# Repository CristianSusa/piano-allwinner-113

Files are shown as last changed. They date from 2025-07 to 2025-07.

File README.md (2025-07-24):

# Piano with Dev Board LCPI-PC-T113
This piano is a college project for Embedded Systems and Electronic Systems Design. It uses the LCPI-PC-T113 development board with the Allwinner T113s chip running embedded Debian. The project includes the design of the PCB as well as the design of the enclosure. Notes on the development process are also included.

## Contents
Within this repository, you will find two folders:
* embedded-systems-development
* electronic-system-design

These folders serve as a step-by-step guide on how to construct the piano. They include files, construction notes, and suggestions for improvements in future versions.

Enjoy :D

# The Project
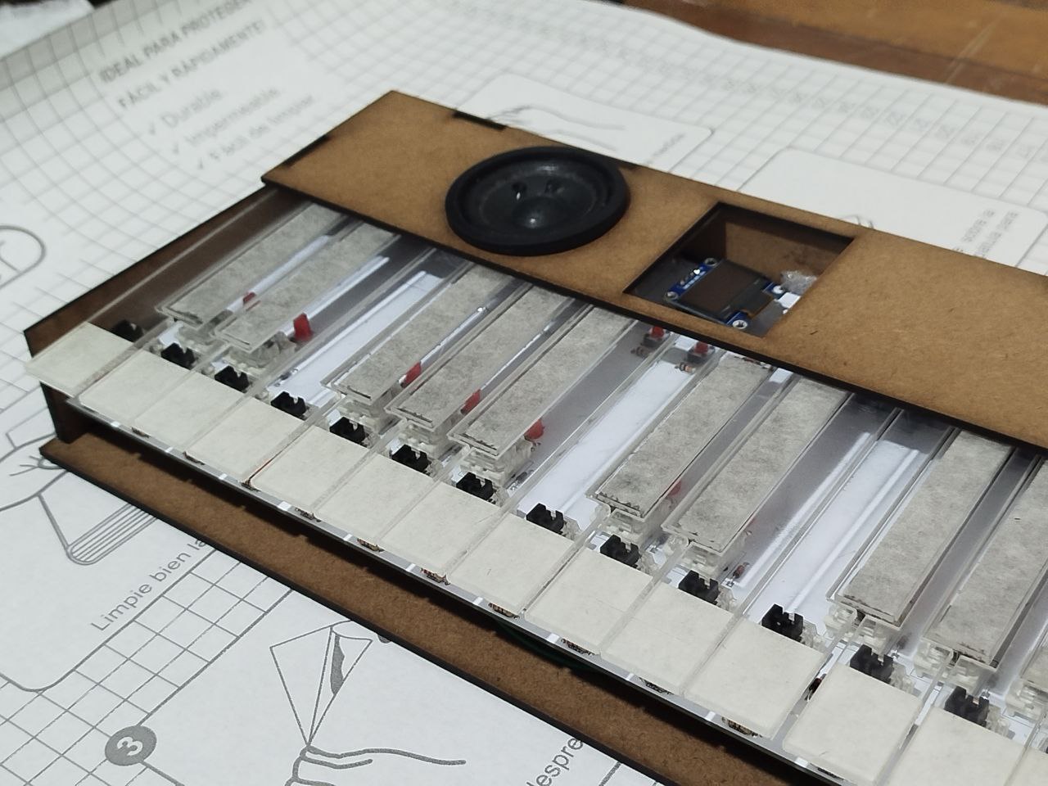
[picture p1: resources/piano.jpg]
piano-image


This piano is designed to provide a low-cost solution for portable musical instruments.

It has two main functions:

1. **Piano Mode** – When a key is pressed, the corresponding note is played through the speaker, just as you would expect from a traditional piano.

2. **Tutor Mode** – In this mode, a few preset songs are available. You can select one, and LEDs will light up to indicate which key to press next, guiding you through the melody step by step.

The piano is intended not only to function as a musical instrument, but also to serve as a learning tool for beginners.

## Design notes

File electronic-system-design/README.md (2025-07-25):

# Electronic Design
This section provides a detailed explanation of the project's electronic design, including key decisions, objectives, and development rationale. It aims to offer a broader perspective on the piano as a finished product, beyond just its functionality.

## The Piano
This project is a university-level design that combines embedded systems and electronic hardware development. It is built around the LCPI-PC-T113 development board, featuring the Allwinner T113s chip running embedded Debian.

The piano integrates both custom PCB and enclosure design, with additional documentation on the development process.

Its goal is to offer a low-cost, portable musical instrument that serves both as a basic piano and as an educational tool. It features two main modes:

- **Piano Mode** – Pressing a key plays the corresponding note through a speaker.
- **Tutor Mode** – LEDs guide the user through preloaded melodies, indicating which key to press next.

The system is designed for beginners, blending play and learning in a compact, accessible format.

## Inspiration
This piano is physically inspired by commercial MIDI controllers such as the **MiniLab 3** by Arturia, the **Akai MPK Mini**, and the **OP-1** by Teenage Engineering.

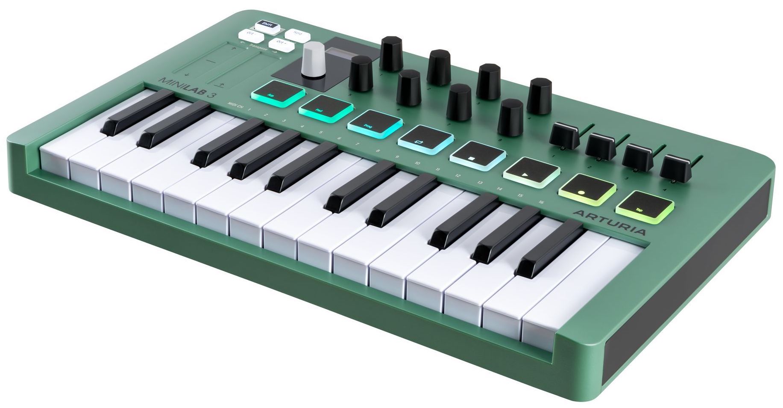
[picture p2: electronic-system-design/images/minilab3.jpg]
MiniLab 3

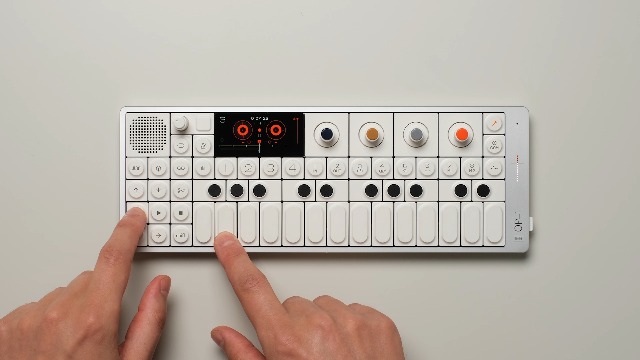
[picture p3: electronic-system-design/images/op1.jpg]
OP-1

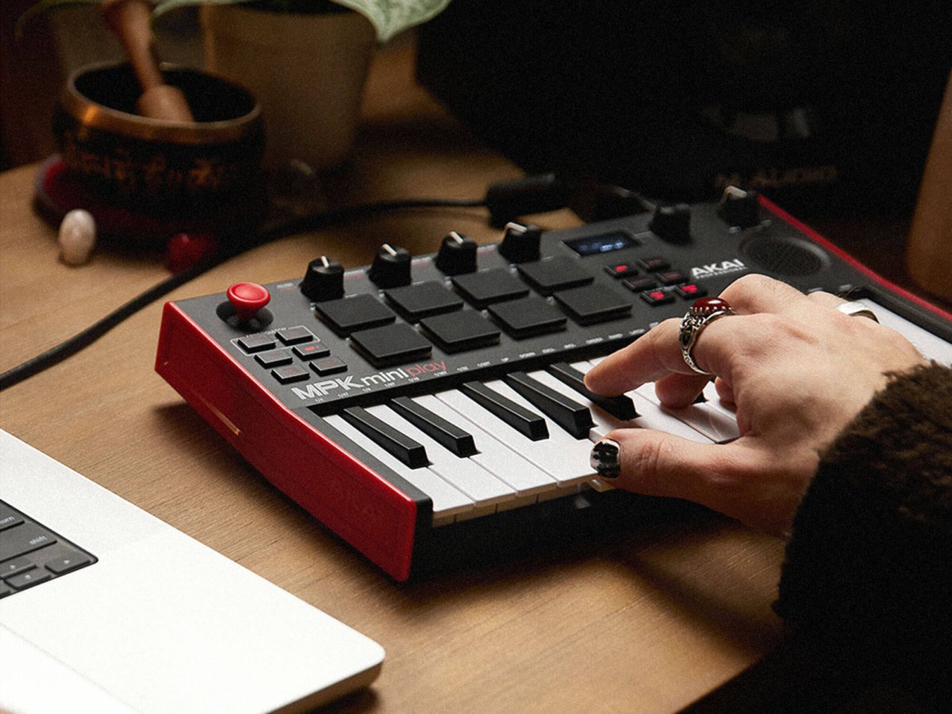
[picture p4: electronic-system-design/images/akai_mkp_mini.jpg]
Akai MPK Mini


The goal is to build a portable device that gives users easy access to a piano wherever they are.

## Objectives
The goal of this project is to create an affordable, efficient, and scalable digital keyboard that works as a standalone device. It features an intuitive user interface.

### Main Objective
Design and build an affordable, energy-efficient, and user-friendly digital keyboard with an intuitive interface, capable of functioning independently and suitable for educational or experimental use.

### Specific Objectives
- **Ensure accessibility and affordability** by keeping the total cost of components below $300,000 COP, making the device viable for students and academic institutions.
- **Promote usability and learning** by including exercises or songs, reinforcing its role as a musical tutor and learning tool.
- **Guarantee energy efficiency and portability** by ensuring the device operates with a current draw of less than 1.5 A, allowing it to be powered by a standard 5V / 2A USB adapter or computer.

## Block Diagram

The proposed system configuration uses the LCPI-PC-T113 development board, featuring the Allwinner T113-S3 chip, as the main controller. A custom daughterboard (the PCB designed in this course) interfaces with it to connect the piano peripherals.

This separation of boards allows modularity: the main board can be reused in future projects, while the daughterboard is application-specific.

The system consists of five main modules:

- **Piano Inputs** – Controls 25 keys (from C4 to C6, covering 2 octaves) arranged in a 5×5 matrix. A *74HC595* shift register activates the columns, while a *74HC165* shift register reads the row states.
  - Shift registers reduce the number of required GPIOs and allow scalable input/output control.
  - ✅ *Pro*: Efficient use of GPIOs with minimal pin usage.
  - ❌ *Con*: Adds a small delay due to serial communication and requires precise clocking.

- **User Interface** – Includes an OLED display and three menu buttons.
  - A minimal interface was chosen to ensure simplicity and ease of navigation for all users.
  - ✅ *Pro*: Clear feedback and interaction with minimal components.
  - ❌ *Con*: Limited interactivity and no text input options.

- **Piano Outputs** – Manages 25 LEDs (one per key) using two *74HC595* shift registers in a 5×5 matrix. Audio output is routed from the board’s headphone jack to an 8-ohm speaker.
  - Using a matrix configuration minimizes wiring and enables efficient LED control in tutor mode.
  - ✅ *Pro*: Clear visual guidance during learning.
  - ❌ *Con*: Cannot light multiple arbitrary combinations without flickering unless advanced multiplexing is implemented.

- **Power** – Powered via a USB-C port providing 5V @ 2A, allowing compatibility with standard smartphone chargers.
  - USB-C is a modern standard and widely available.
  - ✅ *Pro*: Universal and accessible power source.
  - ❌ *Con*: Some connectors have mechanical instability depending on the cable used.

- **Serial Communication and Data** – Includes SD card storage and USB to TTL serial communication used during development and booting.
  - External storage and serial communication simplify testing and firmware updates.
  - ✅ *Pro*: Easy debugging and access to external data.
  - ❌ *Con*: Required workaround (jumpers) due to missing TX/RX pins in the schematic.

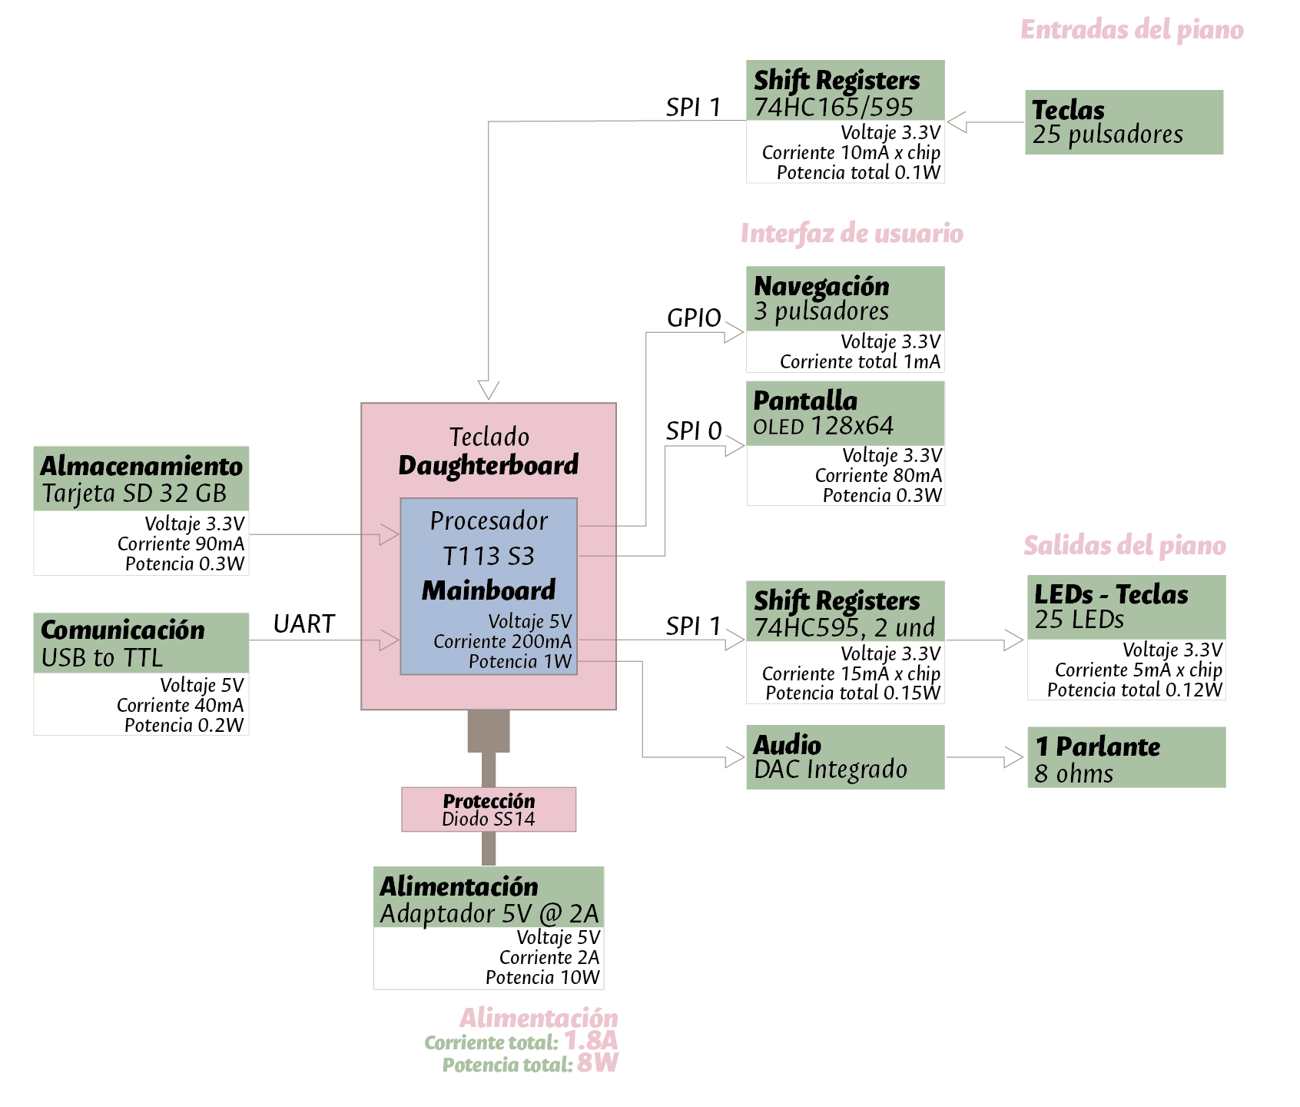
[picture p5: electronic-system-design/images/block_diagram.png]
block diagram


## Electrical Schematic

A total of 19 pins are used to connect the processor to the piano's peripherals. The image below shows the pinout configuration:

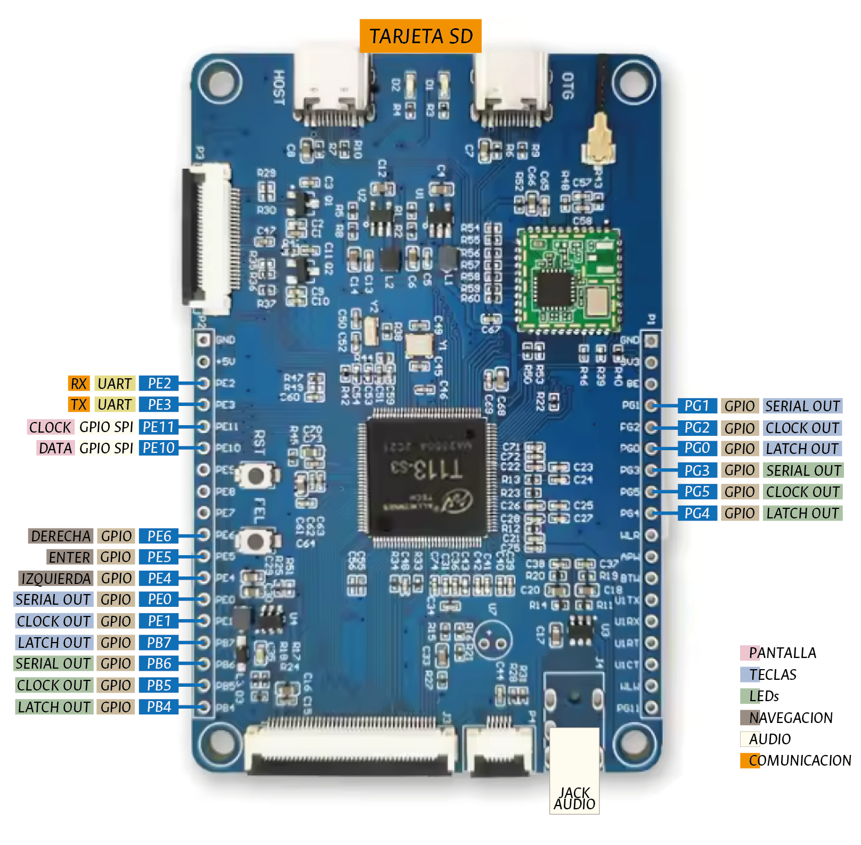
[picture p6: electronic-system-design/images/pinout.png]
pinout


This layout was chosen to optimize routing and prioritize low-latency signals, like the key matrix and OLED interface.

The following sections explain how each module works and how the components are connected. All images are taken from the project schematic file `piano_pcb.kicad_sch`, available at `./resources/pcb/piano_pcb`.

### Keys Matrix
A 5×5 matrix is used to detect key presses, allowing us to read 25 distinct notes. A *74HC595* shift register sequentially activates each column, and a *74HC165* reads the row values. The switches are configured with pull-down resistors: a pressed key outputs logic `1`, and an unpressed key outputs `0`.

- ✅ *Pro*: Scalable and compact solution for multiple key inputs.
- ❌ *Con*: Requires careful debouncing and timing control in software.

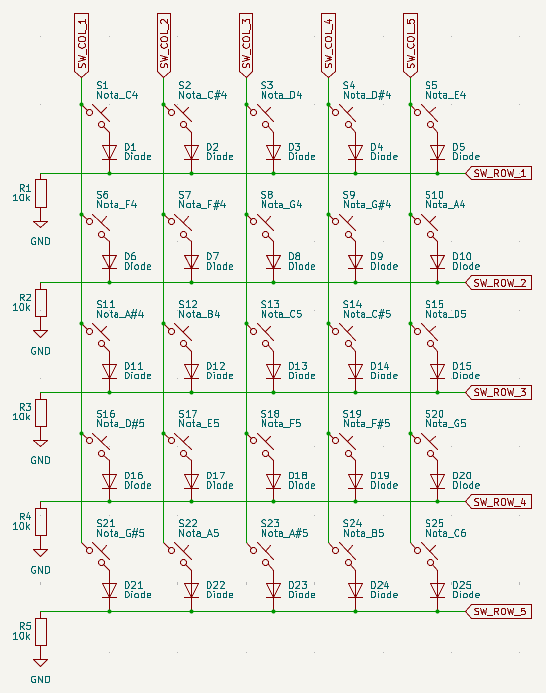
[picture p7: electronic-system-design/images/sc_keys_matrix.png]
sc_keys_matrix

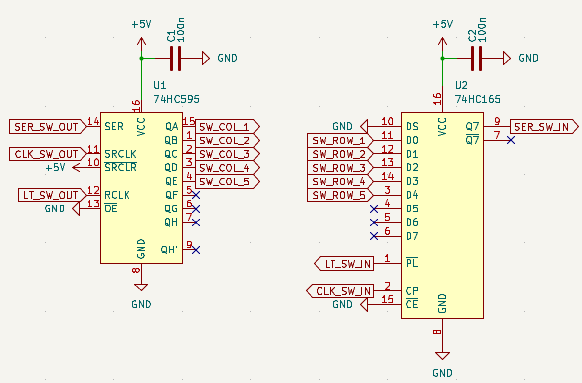
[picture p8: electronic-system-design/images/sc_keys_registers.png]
sc_keys_registers


### LEDs Matrix
Another 5×5 matrix is used to control the LEDs, which are mainly used in tutor mode to highlight the next key to press. Two *74HC595* shift registers manage the LED activation. LEDs use a pull-down configuration: a LED lights up when its cathode is at logic `1` and its anode is at logic `0`.

Coupling capacitors were used in the four integrated circuits to ensure proper power connection.

- ✅ *Pro*: Clean and organized visual feedback system.
- ❌ *Con*: Without current control, simultaneous activation of many LEDs can overload the system.

sc_leds_matrix
sc_leds_registers

### I2C Screen
Initially, a 240×240 SPI screen was proposed for the menu interface. However, due to technical issues and budget/time constraints, we opted for a 128×64 I2C OLED display using the SSD1306 controller.

- ✅ *Pro*: Easy to integrate, widely supported, and consumes less power.
- ❌ *Con*: Lower resolution limits UI complexity.

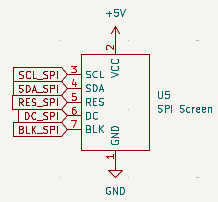
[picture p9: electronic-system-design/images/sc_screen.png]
sc_screen


### Menu Buttons
Three buttons (`Left`, `Enter`, and `Right`) allow the user to navigate the interface. All buttons use a pull-down configuration: pressing a button results in logic `1`, and releasing it results in logic `0`.

- ✅ *Pro*: Simple and intuitive user interaction.
- ❌ *Con*: Limited to basic menu navigation without multi-directional input.

Once the device is powered on and the application starts, the main menu is displayed with two options:

1. **Piano Mode** – Basic mode in which pressing a key plays the corresponding sound.
2. **Tutor Mode** – Guides the user through one of four built-in songs: `Estrellita`, `Cumpleaños Feliz`, `Los Pollitos`, and `Piratas del Caribe`.

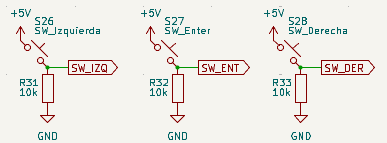
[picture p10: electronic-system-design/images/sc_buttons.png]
sc_buttons


### Power Input
Power is supplied through a USB-C female connector, chosen for its compatibility with most modern chargers. However, this decision turned out to be suboptimal — in practice, the connection can be unstable depending on the cable or connector, causing accidental shutdowns with slight movement.

To protect the circuit, an SS14 diode prevents reverse current and voltage spikes. Two 5.1kΩ resistors to ground ensure the USB-C port is used strictly for power and limits voltage to 5V.

- ✅ *Pro*: Broad compatibility and compact form factor.
- ❌ *Con*: Susceptible to disconnection if cable or socket is loose.

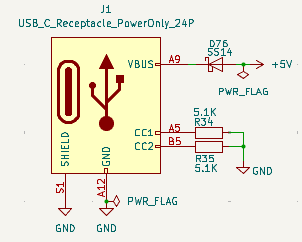
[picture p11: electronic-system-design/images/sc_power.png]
sc_power


### Dev Board Integration
A custom symbol and footprint were created in KiCad to represent the LCPI-PC-T113 board and ensure proper alignment of connections.

The schematic shows the necessary connections for:
- **Shift register control** – `SER`, `CLK`, `LATCH`
- **Menu buttons** – input GPIOs for `Left`, `Enter`, and `Right`
- **OLED display** – `SDA`, `SCL` for I2C communication

- ✅ *Pro*: Accurate mapping of dev board pins in PCB layout.
- ❌ *Con*: Omission of serial TX/RX was a critical error, requiring manual correction with jumpers.

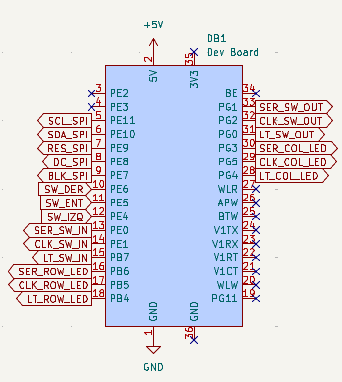
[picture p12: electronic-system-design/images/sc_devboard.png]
sc_devboard


The serial communication was originally assigned to pins `PE2` and `PE3`, as shown in the pinout image above. However, these connections were not included in the schematic — a design oversight. As a workaround, jumpers were added in the physical prototype. This is one of the areas identified for improvement in future revisions.

## Materials
The piano consists of low-cost electronic components, including standard switches, LEDs, and diodes. The two most expensive parts of the build are the LCPI-PC-T113 development board and the custom-designed daughterboard (PCB). These will be detailed further in the cost breakdown.

Below is a list of the main components used:

- 25 × Tactile switches (1 per key)
- 25 × Red LEDs (1 per key for tutor feedback)
- 25 × 220 Ω resistors (for LED current limiting)
- 50 × 1N4148 diodes (for matrix input protection)
- 8 × 10 kΩ resistors (for pull-down configurations)
- 3 × 4-leg tactile menu switches (Left, Enter, Right)
- 4 × 8×2 pin sockets (for shift register and board connections)
- 3 × 74HC595 shift registers (2 for LED matrix, 1 for key matrix column activation)
- 1 × 74HC165 shift register (for key matrix row reading)
- 4 × 100 nF ceramic capacitors (for decoupling)
- 1 × SS14 Schottky diode (for reverse polarity protection)
- 2 × 5.1 kΩ resistors (for USB-C power configuration)
- 1 × USB-C female port (for 5V power input)
- 2 × Female header grids (to interface with dev board)

All components were selected for availability, cost-efficiency, and compatibility with hand soldering and prototyping.

## PCB Design

KiCad and LayoutEditor were the main tools used to design the PCB. The complete KiCad project is available at `./resources/pcb/piano_pcb`.

Returning to our five main modules, this section covers the design process for each one.

---

### Piano Inputs

The key matrix relies on mechanical keyboard switches and diodes. [This video](https://www.youtube.com/watch?v=8WXpGTIbxlQ) provided valuable guidance on mechanical keyboard design and was used as a reference. Its symbol and footprint library was also integrated and is available in `./resources/pcb/piano_pcb/Resources`.

Each note has a dedicated LED, so the layout prioritizes compactness while replicating a traditional piano key arrangement. Diodes are placed to the left of each key to prevent ghosting, and LEDs are positioned above or below the switch based on the note's vertical position.

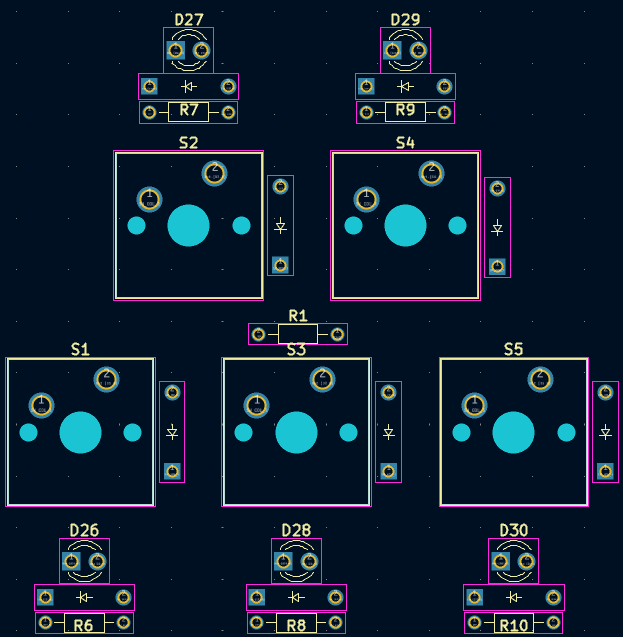
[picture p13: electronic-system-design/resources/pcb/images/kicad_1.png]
kicad_1

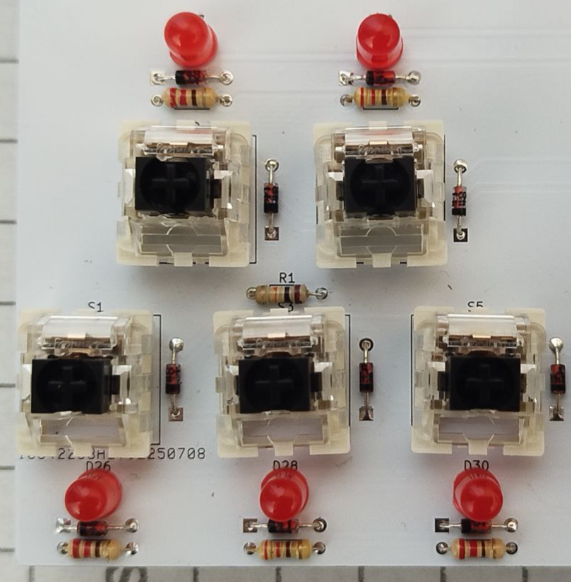
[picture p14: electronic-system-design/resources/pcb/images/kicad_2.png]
kicad_2


Footprint used for the key switches:

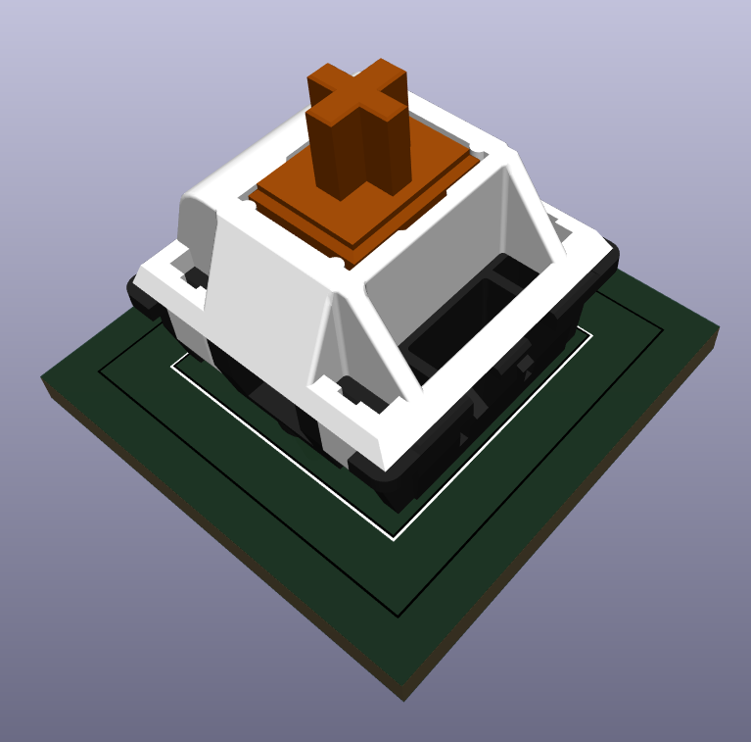
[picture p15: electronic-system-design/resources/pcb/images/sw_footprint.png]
sw_footprint


### Piano Outputs

The LEDs are a core feature for the tutor mode. Each LED has a dedicated 220 Ω current-limiting resistor and a 1N4148 diode to avoid unwanted activation due to matrix effects (ghosting).

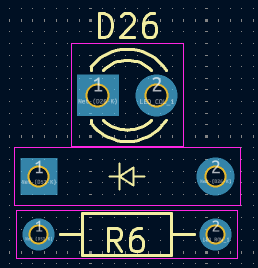
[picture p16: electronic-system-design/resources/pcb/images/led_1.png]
led_1

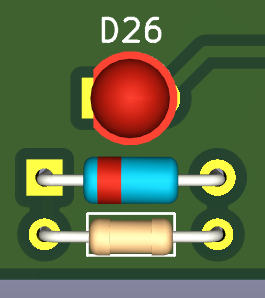
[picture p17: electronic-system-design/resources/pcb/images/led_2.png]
led_2

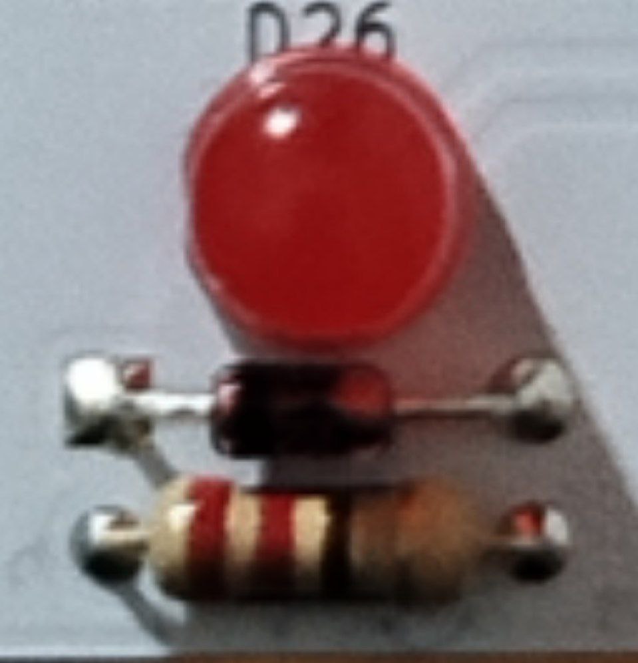
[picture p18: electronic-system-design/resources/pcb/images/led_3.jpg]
led_3


### User Interface

The menu buttons and display are located on the top edge of the piano for visibility and accessibility. The OLED screen symbol and footprint were manually created based on an initial SPI version, though later adapted to a 128×64 I2C display (SSD1306). The chosen I2C pins remained the same for mechanical compatibility.

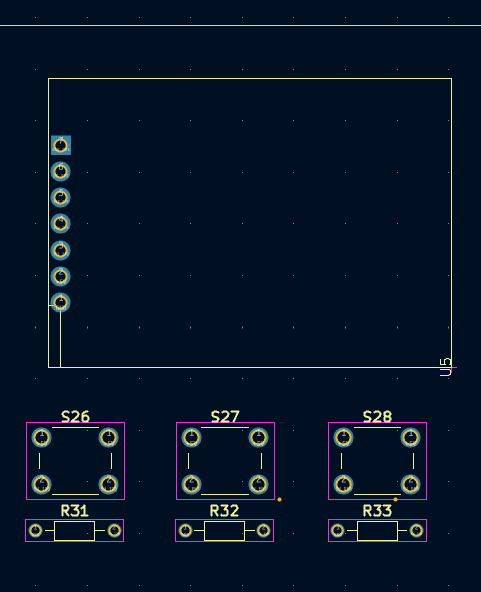
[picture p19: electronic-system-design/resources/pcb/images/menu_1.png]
menu_1

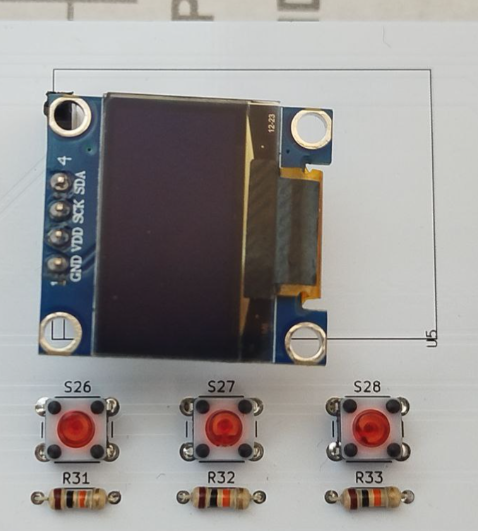
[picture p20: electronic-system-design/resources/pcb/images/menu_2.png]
menu_2


### Power Input

This section presented the most soldering challenges due to two surface-mount components: the USB-C female connector and the SS14 Schottky diode. These were the only compatible models available in the local market and required careful placement.

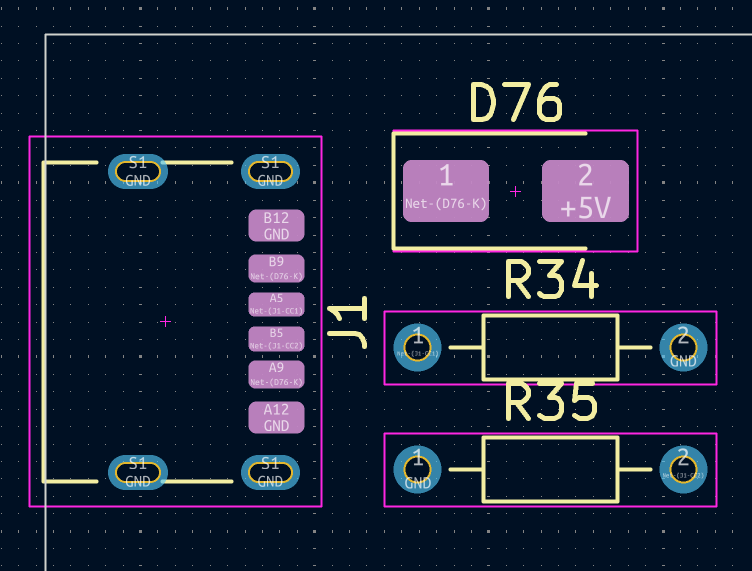
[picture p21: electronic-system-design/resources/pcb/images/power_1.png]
power_1

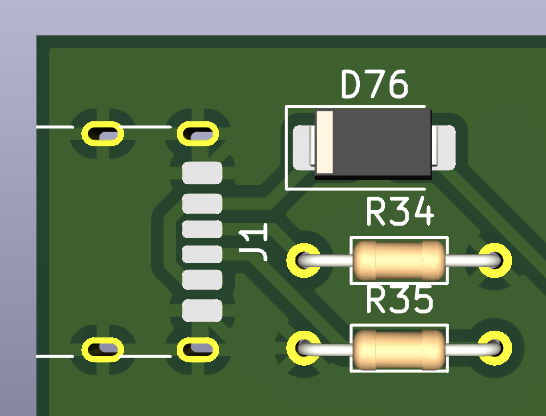
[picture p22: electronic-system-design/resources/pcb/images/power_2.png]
power_2

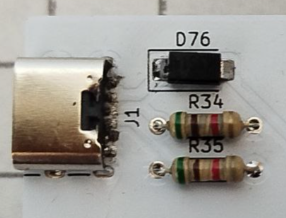
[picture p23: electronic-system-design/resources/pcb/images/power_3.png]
power_3


### Devboard Interface

A custom footprint was created to place female headers in a "shield-like" fashion, aligning with the LCPI-PC-T113 board’s pinout. This allows reliable and modular interfacing between the devboard and the daughterboard.

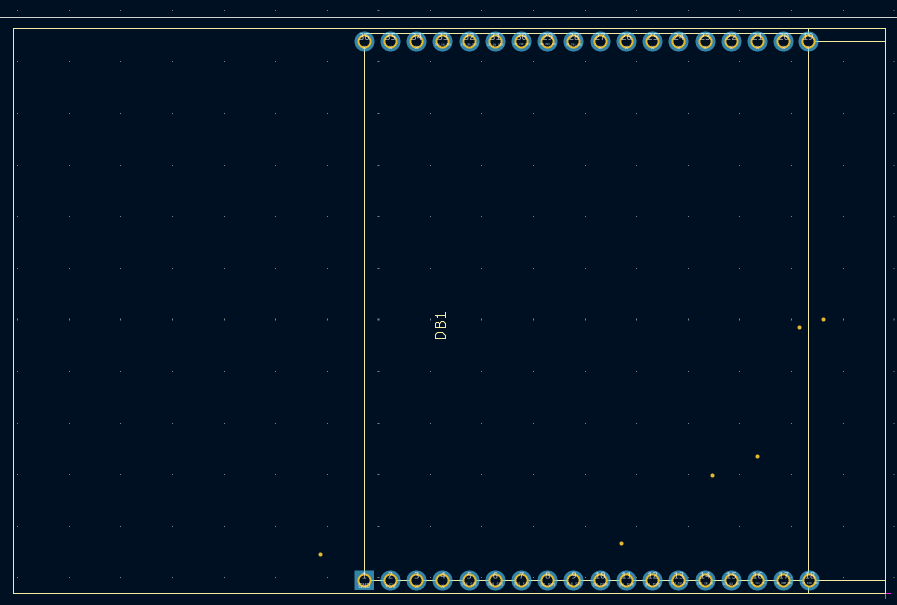
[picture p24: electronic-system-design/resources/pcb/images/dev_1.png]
dev_1


---

### Construction

The PCB routing was done using the `FreeRouting` tool. All traces were set to 0.5 mm width, which is sufficient given the low current requirements of each signal. Both top and bottom layers were used, with several vias placed throughout the board—particularly around the key and LED matrices—due to the high density of connections.

The PCB was manufactured by **JLCPCB**, and the production files are available at `./resources/pcb/piano_pcb/production`.

Below are some images of the PCB layout and the assembled board:

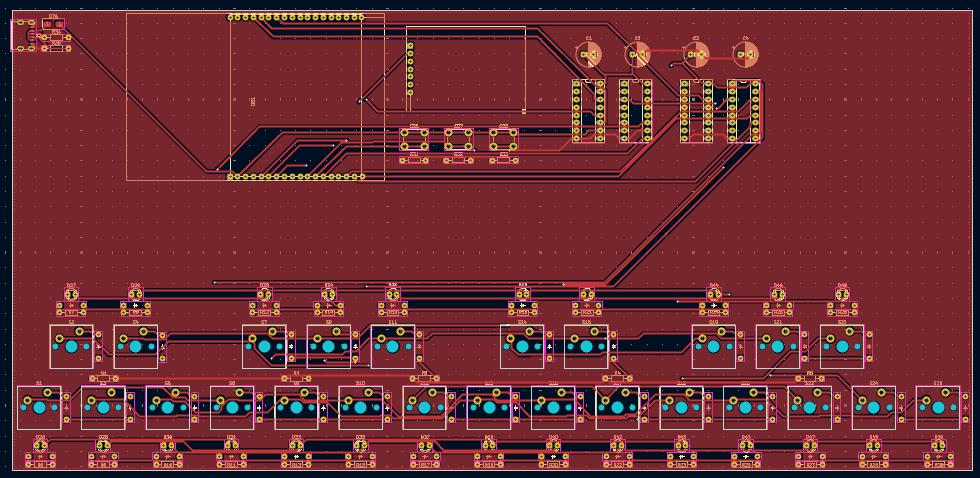
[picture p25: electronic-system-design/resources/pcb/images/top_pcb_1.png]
top_pcb_1

top_pcb_2
bot_pcb_1
bot_pcb_2

final_pcb_kicad

Final soldered board:

final_pcb

## Case Design

The case was designed using **Adobe Illustrator**, vectorizing the pieces for laser cutting. The main PCB measures **314 mm × 150.5 mm**, and additional clearance was considered for the height of the devboard underneath (~15 mm), as well as the switches and screen above (~17.5 mm).

The design consists of two main parts:

1. **The Case** – Made of MDF and laser cut to encase the piano. It protects the electronics and gives structural support.

mdf

2. **The Keycaps** – A piece of laser-cut acrylic simulates the shape of piano keys. The transparency allows LED light to shine through during tutor mode, guiding the user visually.

acr

The Adobe Illustrator and PDF files used in the process are available at `./resources/case/files`.

### Case Construction

Once all pieces were laser cut, assembly was done manually. The result is a lightweight, solid enclosure with custom-fit keycaps:

case_1
case_2
case_3

## User Menu

As mentioned earlier, three buttons (`Left`, `Enter`, and `Right`) are used to navigate the user interface. All buttons follow a pull-down configuration: pressing a button sends logic `1`, and releasing it returns to logic `0`.

Upon powering on the device and loading the main application, the user is presented with the main menu featuring two options:

1. **Piano Mode** – A classic mode where each key press immediately plays a corresponding note.
2. **Tutor Mode** – A guided mode where the user can select one of four built-in songs: `Estrellita`, `Cumpleaños Feliz`, `Los Pollitos`, and `Piratas del Caribe`.

Below is a simplified flow diagram of the navigation logic:

flow_diagram

Some photos of the interface in action:

oled_1
oled_2

## Prototype
The final piano is a mix of effort, enthusiasms, challenges, copper, mdf, acrilic, electrons and music. Here are some photos.

pro_1
pro_2
pro_3
pro_4

## Technical Decisions Justification

### Choice of Main Microcontroller or IC
The project uses the **LCPI-PC-T113** development board based on the **Allwinner T113-S3** processor. This chip was selected because it can run a full embedded Debian OS, providing enough processing power to handle multiple peripherals (display, inputs, outputs, audio) while offering flexibility for expansion. Its ability to support real-time applications (like those built with Faust) made it an ideal platform for this kind of project.

### Technology Type: THT, SMD, or Mixed
A **mixed technology approach** was used. Most components (resistors, diodes, capacitors, shift registers, buttons, LEDs) are **THT (Through-Hole Technology)**, selected for ease of manual soldering and local availability. However, some components such as the **USB-C connector** and the **SS14 diode** are **SMD (Surface-Mount Device)** because they were only available in that format.

This hybrid approach balanced manufacturability, cost, and the team's ability to assemble the board by hand.

### Number of Layers
The PCB was designed with **two layers (top and bottom)**. This was necessary to route the large number of signals—especially in the key and LED matrices—without increasing manufacturing costs. Vias were used to interconnect the layers where needed, allowing for a more compact and efficient layout.

### Power and EMI Considerations
Power is supplied through a **USB-C female connector**, delivering 5 V at 2 A. A **Schottky SS14 diode** was added to protect the circuit from reverse current or voltage spikes. Two **5.1 kΩ pull-down resistors** ensure the port is used for power only. The overall current draw of the system is low, so thermal or EMI (electromagnetic interference) concerns were minimal. However, filtering and shielding could be added in future revisions if needed.

### Standards Applied
While no formal certification standard was strictly followed, the design referenced general best practices from the **IPC-2221** standard, including trace width, clearance, and via placement. These practices helped ensure a manufacturable PCB and reliable electrical performance during testing.

---

## Possible Improvements

- **Redesign the pinout** to include the `TX` and `RX` serial communication lines. These were missing in the original schematic and had to be patched with jumpers on the prototype.
- **Replace or reposition the USB-C connector** to improve physical connection stability. In its current location, small movements can interrupt power and shut down the piano.
- **Use dedicated LED drivers**, such as the TLC5940, to enable PWM per channel, reduce sound delay, and allow multiple notes to play simultaneously (polyphony).
- **Reintroduce the SPI screen** if software support issues are resolved, to take advantage of its higher resolution for better UI design.
- **Optimize power consumption** by adding sleep modes or auto-shutdown after inactivity.
- **Add EMI protection and filtering** for use in more demanding environments or for future compliance with electronic certification.
- **Follow full IPC standards** (such as IPC-2222 for general-purpose PCBs) to improve reliability, documentation quality, and potential for scaling production.

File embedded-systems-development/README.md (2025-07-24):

# Embedded System
This part of the piano project follows the instructions provided by Carlos Iván Camargo Bareño, our instructor for the semester. He shared a book and a guide detailing how to set up the embedded system on our board. The text is available in the `resources` folder for further reference.

We chose the LCPI-PC-F133-T113-D1S-V1.3 development board, available at AliExpress.

This board features a dual-core ARM Cortex-A7 CPU, powered by the Allwinner T113-S3 SOC.

1. [Buildroot](#buildroot)
    1. [Clone the repository](#1-clone-the-repository)
    2. [Kernel configuration](#2-kernel-configuration)
    3. [Toolchain](#3-toolchain)
    4. [U-boot setup](#4-u-boot-setup)
    5. [Creating the SD](#5-creating-the-sd)
    6. [Creating image](#6-creating-image)
    7. [Debian](#7-debian)
    8. [Enjoy](#8-enjoy)
2. [Pins and Peripherals](#pins-and-peripherals)
3. [Device Tree](#device-tree)
    1. [The .dtsi File](#the-dtsi-file)
    2. [The .dts File](#the-dts-file)
4. [Rebuilding](#rebuilding)
5. [The Code](#the-code)
    1. [Matrices](#matrices)
    2. [Sound](#sound)
    3. [Screen](#screen)
    4. [Main Menu](#main-menu)
6. [The piano](#the-piano)

## Buildroot
Buildroot is a tool that helps in the construction of embedded systems, similar to Yocto, OpenWRT, and other build systems. We are using Buildroot to create the system image. Below is the step-by-step guide.

### 1. Clone the repository
First, you will need to run this commands:

```
git clone https://github.com/yuzukihd/Buildroot-YuzukiSBC
cd Buildroot-YuzukiSBC
source envsetup.sh
lunch
make mangopi_mq_dual_defconfig
make -j10 # Adjust according your machine, running the nproc command on the terminal helps
```
You will encounter three errors during this process. While running `make`, it will attempt to download some files that are no longer available at the specified URLs. Here's how to resolve them:

1. Within the `resources` folder you have `v1.0.1.tar.gz`. You should move this file to `buildroot/dl/uboot/`.
2. Within the `resources` folder you have `1.0.0.tar.gz`. You should move this file to `buildroot/dl/linux`.
3. Within the `resources` folder you have `mkbootimg`. You should move this file to the folder of binaries of your computer, you can use `cd /bin/` and copy the file.
4. Other errors may advise you to install different packages, they are usually available with `apt-get install`.

### 2. Kernel configuration
The last step was executed using the default configuration. Now, we need to modify the configuration file to add support for the specific devices we want to use. Run the following command to open the menu configuration:
```
make linux-menuconfig
```
Now, make sure to enable (or disable) the following nodes:
```
Device Drivers
    GPIO Support --->
        <*> /sys/class/gpio/
        <*> Debug GPIO calls

Device Drivers
    Network device support --->
        PHY Device support and infrastructure --->
            < > RealTek RTL-8363NB Ethernet Adapter support

Device Drivers
    I2C support --->
        I2C Hardware Bus Support --->
            <*> GPIO-based bitbanging I2C

Device Drivers
    Graphics support --->
        Frame buffer Devices --->
            <*> Support for frame buffer devices --->
                [*] Simple framebuffer support
                <*> Solomon SSD1307 framebuffer support

File systems
    <*> Old Kconfig name for Kernel automounter support
    <*> Kernel automounter support (supports v3, v4 and v5)
    < > SquashFS 4.0 - Squashed file system support

General setup
    <*> Control Group support
    [*] Support for paging of anonymous memory (swap)
```
You can now rebuild your image with the following commands
```
make -j12 linux-rebuild
make -j12
```

### 3. Toolchain 
These tools will help us in the compilation proccess, the `TOOLCHAIN` folder is available at `resources`.
Just make sure to add the this folder to the path with `export PATH=$HOME/TOOLCHAIN/gcc-linaro-7.2.1-2017.11-x86_64_arm-linux-gnueabi/bin:$PATH`

### 4. U-boot setup
Within the `resources` folder you also have the `v1.0.1.tar.gz` folder. You need to unpack that and patch the instructions with some files available at `patch_uboot`, also available in `resources`. This way:

```
tar zxvf v1.0.1.tar.gz
cd u-boot-2018-1.0.1

patch -p1 < ../patch_uboot/0001-add-support-for-buildroot.patch
patch -p1 < ../patch_uboot/0002-fix-uboot-disable-dtc-selfbuilt.patch
patch -p1 < ../patch_uboot/0003-fix-uboot-support-for-buildroot-dts-file.patch
patch -p1 < ../patch_uboot/0004-fix-No-rule-to-make-target-sunxi_challenge.patch
patch -p1 < ../patch_uboot/0005-fix-yylloc.patch

cp ../patch_uboot/uboot_mangopi_mq_dual_defconfig configs/
cp ../patch_uboot/sun8i-mangopi-mq-dual-uboot.dts ./arch/arm/dts/
cp ../patch_uboot/sun8iw20p1-soc-system.dtsi arch/arm/dts/
```
You’ve just copied a `.dts` and a `.dtsi` file. These are **not** the device tree files you will modify for future tests involving pins in your project. They are basic device tree files used to initialize essential hardware and boot the root filesystem.

For pin configuration and other hardware customizations, you’ll need to locate and edit the appropriate board-specific device tree files later in the process. We will check that in a second.

Now, you need open the menu configuration:

```
make CROSS_COMPILE=arm-linux-gnueabihf- ARCH=arm uboot_mangopi_mq_dual_defconfig
make CROSS_COMPILE=arm-linux-gnueabihf- ARCH=arm menuconfig
```
and make sure to enable the following options
```
Command line interface --->
    Boot commands --->
        [*] bootz
    [*] go

Device Tree Control --->
    Provider of DTB for DT control --->
        [*] Provided by the board at runtime
```
And make the instructions:
```
make CROSS_COMPILE=arm-linux-gnueabihf- ARCH=arm
```
At the end, you will have a file named `u-boot-sun8iw20p1.bin`. Please copy this file to `your-path/Buildroot-YuzukiSBC/buildroot/output/images`. We will need that file in the future;)

### 5. Creating the SD
Finally, we are going to create the partitions and add the necessary files to our SD card to make everything work.

According to the image:
buildroot_table

* `boot_package.fex` includes `u-boot-sun8iw20p1.bin` and `sun8i-mangopi-mq-dual-linux.dtb`. These are essential for the initial boot stage of the system.
* `boot.vfat` includes `boot.img`, `zImage`, and `sun8i-mangopi-mq-dual-linux.dtb`. These files contain the kernel, device tree, and bootloader required to start the operating system.

First, we have to copy the `boot_package.fex` on the requiered location, please run the following commands:
```
cd your-path/Buildroot-YuzukiSBC/buildroot/output/images
./dragonsecboot -pack boot_package.cfg
sudo dd if=boot_package.fex of=/dev/sdX(CHANGE) bs=1k seek=16400
```
We have just completed the initial boot. Now, we need to ensure that the partitions are correctly created on the SD card and have the appropriate sizes.
```
cd your-path/Buildroot-YuzukiSBC/buildroot/output/images
sudo dd if=sdcard.img of=/dev/sdX(CHANGE)

sudo fdisk /dev/sdX(CHANGE)

Command (m for help): p

Device          Start   End         Sectors     Size    Type
/dev/sda1       35360   36383       1024        512K    Linux filesystem
/dev/sda2       36384   36639       256         128K    Linux filesystem
/dev/sda3       36640   36895       256         128K    Linux filesystem
/dev/sda4       36896   102431      65536       32M     Linux filesystem
/dev/sda5       104448  62333918    62229471    29,7G   Linux filesystem
    
Borrar partición: d
Crear nueva partición n
Gardar cambios: w
```
These steps resize the fifth partition. Now, we just need to format it with the correct filesystem.

```
sudo mkfs.ext4 /dev/sdX5(CHANGE)
```
**PLEASE UNPLUG AND PLUG ONCE AGAIN THE SD CARD TO MAKE SURE THE CHANGES ARE SAVED**

### 6. Creating image
Now, we just need to add the image to our SD Card with the following commands:
```
cd your-path/Buildroot-YuzukiSBC/buildroot/output/images
mkbootimg --kernel zImage --output boot.img
sudo cp zImage boot.img sun8i-mangopi-mq-dual-linux.dtb /media/USER/FOURTH-PARTITION/ # That fourth partition is usually something with 8 characters like 12B7-6A23 in my case
```

### 7. Debian
The last step is to load an OS to the SD Card.
Within the `resources` folder you have `debian_bookworm`. You just need to copy the files into the fifth partition, the one we just resized.
```
cd your-path/debian_bookworm
sudo cp -avr * /media/USER/FIFTH-PARTITION/  # That fifth partition is usually something with a lot of characters like d4ab1e98-2104-4b8f-8526-55a987f8b082 in my case
```
For further details on this process, the guidebook contains a step-by-step guide on how to download and set up the OS.

### 8. Enjoy
Now you're all set! You can communicate with your board from your computer over the serial connection using Minicom. :D

## Pins and Peripherals
As mentioned at the beginning, this project aims to be a tutor for piano learners. To accomplish that, we need to have three main things:

* A piano keyboard that sounds
* A system to guide the user on which key to press next
* A menu interface for the user to interact with the device

We proposed the construction of a daughter board, a shield-like board, with the necessary elements to achieve our three specifications. More details on this process are provided in another section of this repo, `electronic-system-design`, which includes files, key points of the design, the methodology used, and the physical construction of the piano.

However, it is important to mention a couple of things here regarding the pinout.

This board has 36 pins, some of which are part of the PB, PE, and PG banks of pins. More information on that can be found in the documentation included in  [this documentation](https://drive.google.com/drive/folders/1lrqDsxtGl8WvU7o547lT9IkHwGyAHXFU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)

We used MIDI controllers like the MINILAB3, AKAI MPK Mini, and OP-1 from Teenage Engineering as references for our piano. They have 25 keys from C4 to C6.

For the tutor, we proposed one LED per key to instruct the player on "the next key to be pressed."

That is, 25 keys with 25 LEDs. The pins are limited on the board, so we have to reserve some for serial communication, the I2C screen, and some buttons.

The solution is to set up a 5x5 matrix for the keys and a 5x5 matrix for the LEDs, controlled by shift registers. This way, we reduce the pin count from 10 pins for each matrix (20 pins total for keys and LEDs) to just 12 pins, like this:

* Keys: the **74HC595** will activate the columns of the matrix, while the **74HC165** will read the values.
* LEDs: one **74HC595** will activate the columns of the matrix, and the other **74HC595** will activate the rows.

Each shift register uses three pins, and we have four integrated circuits, so that’s 12 pins for the matrices.

The screen, initially proposed to be SPI, was changed to I2C with bit-banging, and 3 buttons are used for the user interface.

Those are the pins used for this project. Below, you will find some images for further reference.

### Keys Matrix
keys_matrix
keys_shifts

### LEDs Matrix
leds_matrix
leds_shifts

### Screen and Buttons
screen_menu
buttons_menu

### Dev Board Pinout
dev_board_pinout

## Device Tree
This is how we set up the pins to interact with our kernel and the OS. Here, we define what each pin is used for and which drivers they should include. This is essential when customizing an image to ensure the pins are used correctly.

Keeping the pinout in mind, we configure the pins connected to a shift register or to a button for GPIO. The 3 pins for the screen are also GPIO but are used with I2C bit-banging.

### The .dtsi File
This is a general configuration. Here, we define the pins for the matrices, screen, buttons, and UART. You can see that all of them have `status = "disabled";`. This is for convention; they will be enabled in the next important file, the `.dts`.

You can find this file in `your-path/Buildroot-YuzukiSBC/buildroot/board/allwinner-generic/sun8i-t113/dts/linux/sun8iw20p1-linux.dtsi`

These are the nodes:

#### UART
For serial communication.
```
/ {
    soc: soc@3000000 {
        uart0: uart@2500000 {
            compatible = "allwinner,sun8i-uart";
            device_type = "uart0";
            reg = <0x0 0x02500000 0x0 0x400>;
            interrupts = <GIC_SPI 2 IRQ_TYPE_LEVEL_HIGH>;
            sunxi,uart-fifosize = <64>;
            clocks = <&ccu CLK_BUS_UART0>;
            clock-names = "uart0";
            resets = <&ccu RST_BUS_UART0>;
            uart0_port = <0>;
            uart0_type = <2>;
            status = "disabled";
        };
    }
}
```

#### Keys Matrix, LEDs Matrix, and Buttons
Here, we set the pins to `gpio_in`, making each pin a GPIO port that we can configure via software to send or receive data.
```
/ {
    soc: soc@3000000 {
        pio: pinctrl@2000000 {
            gpio_piano_pins: gpio_piano_pins@0 {
                pins = "PE0", "PE1", "PE4", "PE5", "PE6", "PB7",
                    "PG0", "PG1", "PG2", "PG3", "PG4", "PG5",
                    "PB4", "PB5", "PB6";
                function = "gpio_in";
                drive-strength = <10>;
                bias-disable;
            };
        }
    }
}
```

#### I2C Screen
We define the clock and data pins for the screen. Additionally, we configure some settings of our OLED display, such as width, height, and the driver `ssd1306fb-i2c`. This driver was included in the kernel configuration.
```
/ {
    i2c_gpio: i2c-gpio {
        compatible = "i2c-gpio";
        gpios = <&pio 4 10 GPIO_ACTIVE_HIGH /* SDA = PE10 */
                    &pio 4 11 GPIO_ACTIVE_HIGH>; /* SCL = PE11 */
        i2c-gpio,delay-us = <5>;
        #address-cells = <1>;
        #size-cells = <0>;
        status = "disabled";

            oled_display: oled@3c {
                compatible = "solomon,ssd1306fb-i2c";
                reg = <0x3c>;
                solomon,width = <128>;
                solomon,height = <64>;
                solomon,page-offset = <0>;
                solomon,com-offset = <0>;
                solomon,segment-offset = <0>;
                status = "okay";
            };
    };
}
```

### The .dts File
This is a more specific file with the header `#include "sun8iw20p1-linux.dtsi"`, meaning that includes our previous nodes configuration. Here we enable our devices along with the pins.

You can find this file in `your-path/Buildroot-YuzukiSBC/buildroot/board/mangopi/mq-dual/dts/linux/sun8i-mangopi-mq-dual-linux.dts`

#### UART
```
&uart0 {
	pinctrl-names = "default", "sleep";
	pinctrl-0 = <&uart0_pins_a>;
	pinctrl-1 = <&uart0_pins_b>;
	status = "okay";
};
```

#### Keys Matrix, LEDs Matrix, and Buttons
```
&pio {
    gpio_piano_pins: gpio_piano_pins@0 {
        allwinner,pins = "PE0", "PE1", "PE4", "PE5", "PE6", "PB7",
                "PG0", "PG1", "PG2", "PG3", "PG4", "PG5",
                "PB4", "PB5", "PB6";
        allwinner,function = "gpio_in";
        allwinner,muxsel = <0>;
        allwinner,drive = <1>;
        allwinner,pull = <0>;
    };
}
```

#### I2C Screen
```
&i2c_gpio {
    status = "okay";
};
```

## Rebuilding 
After making any changes within your device tree, you should:

1. Rebuild your image
2. Copy `boot_package.fex` to the appropriate location
3. Copy `boot.img` and `sun8i-mangopi-mq-dual-linux.dtb` to the appropriate location

```
## 1.
make -j10 linux-rebuild
make -j10

## 2.
cd your-path/Buildroot-YuzukiSBC/buildroot/output/images
./dragonsecboot -pack boot_package.cfg
sudo dd if=boot_package.fex of=/dev/sdX(CHANGE) bs=1k seek=16400

## 3.
cd your-path/Buildroot-YuzukiSBC/buildroot/output/images
mkbootimg --kernel zImage --output boot.img
sudo cp zImage boot.img sun8i-mangopi-mq-dual-linux.dtb /media/USER/FOURTH-PARTITION/ # That fourth partition is usually something with 8 characters like 12B7-6A23 in my case
```

---
## The Code
Once the devices and pins are configured, and both the kernel and OS are running, we can start working with the code and building applications.

Most of the development was done directly on the board’s processor via serial port commands. There is only one exception: when working with Faust (more on that later). The general workflow was:

```
# 1. Create the .cpp file
nano your-code.cpp

# 2. Compile it using the appropiate flags, most of the time the -lgpiod since with are working with gpio libraries
g++ your-code.cpp -o your-code -lgpiod

# 3. Test it
./your-code
```

For this project, we started by controlling the shift registers to verify that both the key matrix and the LED matrix worked properly.

Some test code is included in the `code/test_code` folder:

- For the **LED matrix**, the file `test_leds.cpp` turns on the LEDs on the PCB sequentially, from C4 to C6.
- For the **OLED display**, `test_oled_clear_screen.cpp` paints the screen either black or white. This was used to ensure the driver was functioning correctly and the display was receiving data.  

Additionally, the file `test_oled_draw.cpp` tests drawing an image of Patrick (from *SpongeBob*). This helped us understand how image data is handled by the OLED and what to keep in mind when displaying custom graphics.

A key component of the project is sound generation. We used [Faust](https://faust.grame.fr/) to generate sine waves. Starting from a `.dsp` file, we compiled it into an executable that drives the speaker. Here’s how:

```
# 1. Create the .dsp file
nano your-note.dsp

declare options "[osc:on]";
import("stdfaust.lib");
process = os.osc(440.00);
```

```
# 2. Construct the .cpp file and compile it

faust -a alsa-console.cpp -o your-note.cpp your-note.dsp
g++ your-note.cpp -o your-note -lasound

# You will note that the instructions on the guidebook are different, more on that later
```

```
# 3. Test it, your speaker must vibrate 440 times per second

./your-note 
```
Now, let’s take a closer look at the specific code used in this project.

### Matrices
Starting with the keys and LEDs, the file `code/piano/read_notes.cpp` defines the pins used according to the schematic and board pinout. In this setup, the columns are activated one by one while the rows are scanned to detect which key is being pressed. Thanks to a fast sampling rate, key presses are registered quickly, allowing smooth playability.

Due to limitations with how sound is compiled and triggered, we currently detect and play only one note at a time — even though the hardware is capable of detecting multiple simultaneous key presses.

In the tutor mode code — for example, `code/tutor/t_estrellita.cpp` — pin definitions are also provided. It’s important to note that both the key matrix and the LED matrix are configured with **pull-down resistors**, so ensure the logic in the code matches this configuration to avoid unexpected behavior.

### Sound
Once we know which key has been pressed, we need to generate the corresponding sound. In the official guidebook, interrupts are used for this purpose. However, since we’re working with shift registers rather than traditional GPIOs, we couldn’t use interrupts as expected.

Additionally, Faust’s OSC control (used to dynamically change values like frequency) did not work correctly on our team’s development machines. Because of this, we opted to generate each note individually using Faust, from C4 to C6. Each key is mapped to a specific precompiled sound executable.

This was the best working solution at the time, though it comes with some limitations:

- There’s a slight delay between pressing a key and hearing the sound.
- Only one note can be played at a time, even though the hardware can detect multiple key presses.

The 25 individual notes are available in the `code/piano/notes` folder.

### Screen
After some unsuccessful attempts to use an SPI screen, we switched to a more common I2C OLED screen with an SSD1304 controller. Using GPIO bitbanging, we were able to control the screen and display images.

To generate the bitmaps, we used the tool [img2cpp](https://javl.github.io/image2cpp/). However, since the driver was displaying the images incorrectly, we had to manually mirror them before embedding.

You’ll find the screen-related code in `code/oled/o_menu_normal.cpp` and related files. The bitmap is the only thing that changes between files — the rest of the code remains the same.

### Main Menu
To unify all the "modules" and create a simple user interface, we developed `code/main_code.cpp`. This file handles the input from the menu switches and lets you navigate a basic menu. From there, you can choose between **Normal Piano Mode** or **Tutor Mode**, and select a song to play.

---

## The Piano
Some images of the process and the final result:

pcb
pcb-keys
pcb-leds
pcb-screen
pcb-mounted
mdf
final-piano


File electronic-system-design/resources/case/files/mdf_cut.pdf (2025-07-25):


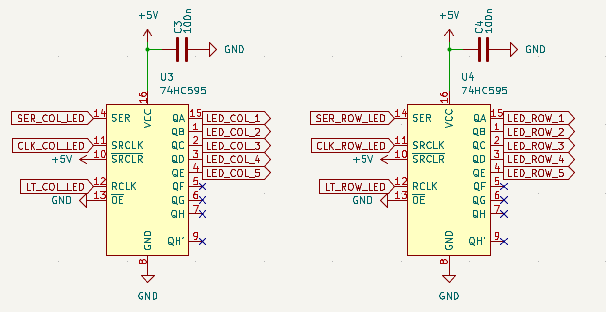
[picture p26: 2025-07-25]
electronic-system-design/images/sc_leds_registers.png

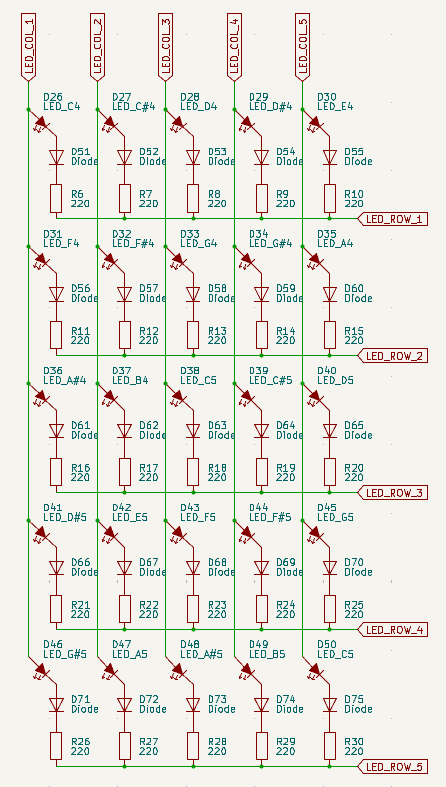
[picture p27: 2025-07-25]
electronic-system-design/images/sc_leds_matrix.png

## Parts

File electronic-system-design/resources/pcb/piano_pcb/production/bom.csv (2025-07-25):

Designator | Footprint | Quantity | Value | LCSC Part #
C1, C2, C3, C4 | CP_Radial_D8.0mm_P3.50mm | 4 | 100n
D1, D10, D11, D12, D13, D14, D15, D16, D17, D18, D19, D2, D20, D21, D22, D23, D24, D25, D3, D4, D5, D51, D52, D53, D54, D55, D56, D57, D58, D59, D6, D60, D61, D62, D63, D64, D65, D66, D67, D68, D69, D7, D70, D71, D72, D73, D74, D75, D8, D9 | Diode_DO-35 | 50 | Diode
D26 | LED_D3.0mm | 1 | LED_C4
D27 | LED_D3.0mm | 1 | LED_C#4
D28 | LED_D3.0mm | 1 | LED_D4
D29 | LED_D3.0mm | 1 | LED_D#4
D30 | LED_D3.0mm | 1 | LED_E4
D31 | LED_D3.0mm | 1 | LED_F4
D32 | LED_D3.0mm | 1 | LED_F#4
D33 | LED_D3.0mm | 1 | LED_G4
D34 | LED_D3.0mm | 1 | LED_G#4
D35 | LED_D3.0mm | 1 | LED_A4
D36 | LED_D3.0mm | 1 | LED_A#4
D37 | LED_D3.0mm | 1 | LED_B4
D38, D50 | LED_D3.0mm | 2 | LED_C5
D39 | LED_D3.0mm | 1 | LED_C#5
D40 | LED_D3.0mm | 1 | LED_D5
D41 | LED_D3.0mm | 1 | LED_D#5
D42 | LED_D3.0mm | 1 | LED_E5
D43 | LED_D3.0mm | 1 | LED_F5
D44 | LED_D3.0mm | 1 | LED_F#5
D45 | LED_D3.0mm | 1 | LED_G5
D46 | LED_D3.0mm | 1 | LED_G#5
D47 | LED_D3.0mm | 1 | LED_A5
D48 | LED_D3.0mm | 1 | LED_A#5
D49 | LED_D3.0mm | 1 | LED_B5
D76 | D_SMA | 1 | SS14
DB1 | Dev_Board_T113 | 1 | Dev Board
J1 | USB_C_Receptacle_HRO_TYPE-C-31-M-17 | 1 | USB_C_Receptacle_PowerOnly_24P
R1, R2, R3, R31, R32, R33, R4, R5 | R_Axial_DIN0204_L3.6mm_D1.6mm_P7.62mm_Horizontal | 8 | 10k
R10, R11, R12, R13, R14, R15, R16, R17, R18, R19, R20, R21, R22, R23, R24, R25, R26, R27, R28, R29, R30, R6, R7, R8, R9 | R_Axial_DIN0204_L3.6mm_D1.6mm_P7.62mm_Horizontal | 25 | 220
R34, R35 | R_Axial_DIN0204_L3.6mm_D1.6mm_P7.62mm_Horizontal | 2 | 5.1K
S1 | MX_PCB_1.00u | 1 | Nota_C4
S10 | MX_PCB_1.00u | 1 | Nota_A4
S11 | MX_PCB_1.00u | 1 | Nota_A#4
S12 | MX_PCB_1.00u | 1 | Nota_B4
S13 | MX_PCB_1.00u | 1 | Nota_C5
S14 | MX_PCB_1.00u | 1 | Nota_C#5
S15 | MX_PCB_1.00u | 1 | Nota_D5
S16 | MX_PCB_1.00u | 1 | Nota_D#5
S17 | MX_PCB_1.00u | 1 | Nota_E5
S18 | MX_PCB_1.00u | 1 | Nota_F5
S19 | MX_PCB_1.00u | 1 | Nota_F#5
S2 | MX_PCB_1.00u | 1 | Nota_C#4
S20 | MX_PCB_1.00u | 1 | Nota_G5
S21 | MX_PCB_1.00u | 1 | Nota_G#5
S22 | MX_PCB_1.00u | 1 | Nota_A5
S23 | MX_PCB_1.00u | 1 | Nota_A#5
S24 | MX_PCB_1.00u | 1 | Nota_B5
S25 | MX_PCB_1.00u | 1 | Nota_C6
S26 | SW_PUSH_6mm_H5mm | 1 | SW_Izquierda
S27 | SW_PUSH_6mm_H5mm | 1 | SW_Enter
S28 | SW_PUSH_6mm_H5mm | 1 | SW_Derecha
S3 | MX_PCB_1.00u | 1 | Nota_D4
S4 | MX_PCB_1.00u | 1 | Nota_D#4
S5 | MX_PCB_1.00u | 1 | Nota_E4
S6 | MX_PCB_1.00u | 1 | Nota_F4
S7 | MX_PCB_1.00u | 1 | Nota_F#4
S8 | MX_PCB_1.00u | 1 | Nota_G4
S9 | MX_PCB_1.00u | 1 | Nota_G#4
U1, U3, U4 | DIP-16_W7.62mm_Socket_LongPads | 3 | 74HC595
U2 | DIP-16_W7.62mm_Socket_LongPads | 1 | 74HC165
U5 | SPI_Screen | 1 | SPI Screen

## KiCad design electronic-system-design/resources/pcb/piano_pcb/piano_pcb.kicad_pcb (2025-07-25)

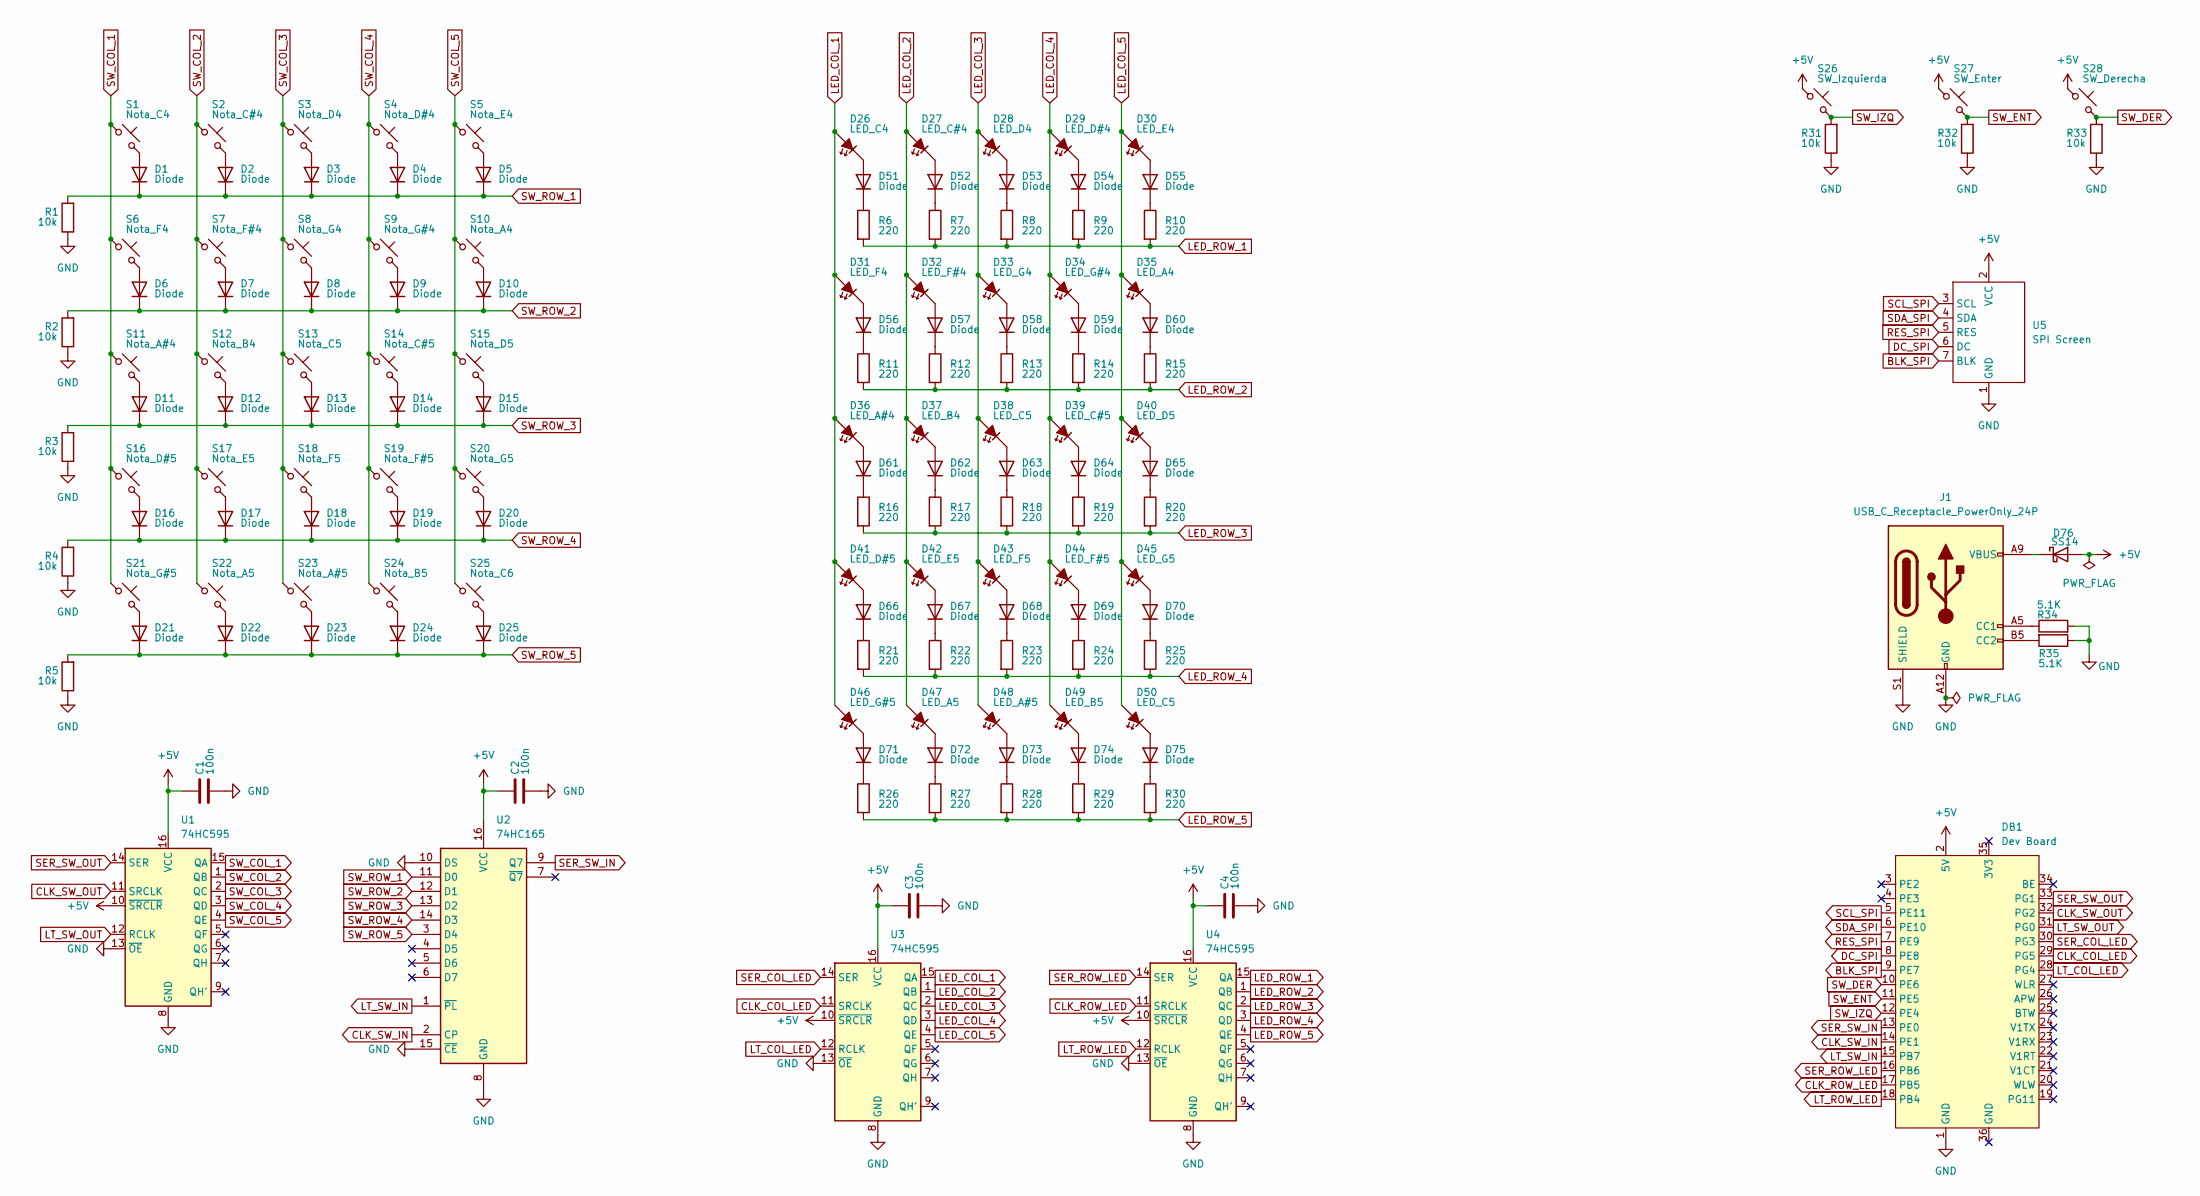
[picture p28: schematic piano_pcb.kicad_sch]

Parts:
C1, C2, C3, C4: 100n; CP_Radial_D8.0mm_P3.50mm
D1, D2, D3, D4, D5, D6, D7, D8, D9, D10, D11, D12, D13, D14, D15, D16, D17, D18, D19, D20, D21, D22, D23, D24, D25, D51, D52, D53, D54, D55, D56, D57, D58, D59, D60, D61, D62, D63, D64, D65, D66, D67, D68, D69, D70, D71, D72, D73, D74, D75: Diode; Diode_DO-35
D26: LED_C4; LED_D3.0mm
D27: LED_C#4; LED_D3.0mm
D28: LED_D4; LED_D3.0mm
D29: LED_D#4; LED_D3.0mm
D30: LED_E4; LED_D3.0mm
D31: LED_F4; LED_D3.0mm
D32: LED_F#4; LED_D3.0mm
D33: LED_G4; LED_D3.0mm
D34: LED_G#4; LED_D3.0mm
D35: LED_A4; LED_D3.0mm
D36: LED_A#4; LED_D3.0mm
D37: LED_B4; LED_D3.0mm
D38, D50: LED_C5; LED_D3.0mm
D39: LED_C#5; LED_D3.0mm
D40: LED_D5; LED_D3.0mm
D41: LED_D#5; LED_D3.0mm
D42: LED_E5; LED_D3.0mm
D43: LED_F5; LED_D3.0mm
D44: LED_F#5; LED_D3.0mm
D45: LED_G5; LED_D3.0mm
D46: LED_G#5; LED_D3.0mm
D47: LED_A5; LED_D3.0mm
D48: LED_A#5; LED_D3.0mm
D49: LED_B5; LED_D3.0mm
D76: SS14; D_SMA
DB1: Dev Board; Dev_Board_T113
J1: USB_C_Receptacle_PowerOnly_24P; USB_C_Receptacle_HRO_TYPE-C-31-M-17
R1, R2, R3, R4, R5, R31, R32, R33: 10k; R_Axial_DIN0204_L3.6mm_D1.6mm_P7.62mm_Horizontal
R6, R7, R8, R9, R10, R11, R12, R13, R14, R15, R16, R17, R18, R19, R20, R21, R22, R23, R24, R25, R26, R27, R28, R29, R30: 220; R_Axial_DIN0204_L3.6mm_D1.6mm_P7.62mm_Horizontal
R34, R35: 5.1K; R_Axial_DIN0204_L3.6mm_D1.6mm_P7.62mm_Horizontal
S1: Nota_C4; MX_PCB_1.00u
S2: Nota_C#4; MX_PCB_1.00u
S3: Nota_D4; MX_PCB_1.00u
S4: Nota_D#4; MX_PCB_1.00u
S5: Nota_E4; MX_PCB_1.00u
S6: Nota_F4; MX_PCB_1.00u
S7: Nota_F#4; MX_PCB_1.00u
S8: Nota_G4; MX_PCB_1.00u
S9: Nota_G#4; MX_PCB_1.00u
S10: Nota_A4; MX_PCB_1.00u
S11: Nota_A#4; MX_PCB_1.00u
S12: Nota_B4; MX_PCB_1.00u
S13: Nota_C5; MX_PCB_1.00u
S14: Nota_C#5; MX_PCB_1.00u
S15: Nota_D5; MX_PCB_1.00u
S16: Nota_D#5; MX_PCB_1.00u
S17: Nota_E5; MX_PCB_1.00u
S18: Nota_F5; MX_PCB_1.00u
S19: Nota_F#5; MX_PCB_1.00u
S20: Nota_G5; MX_PCB_1.00u
S21: Nota_G#5; MX_PCB_1.00u
S22: Nota_A5; MX_PCB_1.00u
S23: Nota_A#5; MX_PCB_1.00u
S24: Nota_B5; MX_PCB_1.00u
S25: Nota_C6; MX_PCB_1.00u
S26: SW_Izquierda; SW_PUSH_6mm_H5mm
S27: SW_Enter; SW_PUSH_6mm_H5mm
S28: SW_Derecha; SW_PUSH_6mm_H5mm
U1, U3, U4: 74HC595; DIP-16_W7.62mm_Socket_LongPads
U2: 74HC165; DIP-16_W7.62mm_Socket_LongPads
U5: SPI Screen; SPI_Screen

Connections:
+5V: C1.1, C2.1, C3.1, C4.1, D76.2 (A), DB1.2 (5V), S26.1, S27.1, S28.1, U1.10 (~SRCLR), U1.16 (VCC), U2.16 (VCC), U3.10 (~SRCLR), U3.16 (VCC), U4.10 (~SRCLR), U4.16 (VCC), U5.2 (VCC)
BLK_SPI: DB1.9 (PE7), U5.7 (BLK)
CLK_COL_LED: DB1.29 (PG5), U3.11 (SRCLK)
CLK_ROW_LED: DB1.17 (PB5), U4.11 (SRCLK)
CLK_SW_IN: DB1.14 (PE1), U2.2 (CP)
CLK_SW_OUT: DB1.32 (PG2), U1.11 (SRCLK)
DC_SPI: DB1.8 (PE8), U5.6 (DC)
GND: C1.2, C2.2, C3.2, C4.2, DB1.1 (GND), J1.A1 (GND), J1.A12 (GND), J1.B1 (GND), J1.B12 (GND), J1.S1 (SHIELD), R1.1, R2.1, R3.1, R4.1, R5.1, R31.1, R32.1, R33.1, R34.2, R35.1, U1.8 (GND), U1.13 (~OE), U2.8 (GND), U2.10 (DS), U2.15 (~CE), U3.8 (GND), U3.13 (~OE), U4.8 (GND), U4.13 (~OE), U5.1 (GND)
LED_COL_1: D26.2 (A), D31.2 (A), D36.2 (A), D41.2 (A), D46.2 (A), U3.15 (QA)
LED_COL_2: D27.2 (A), D32.2 (A), D37.2 (A), D42.2 (A), D47.2 (A), U3.1 (QB)
LED_COL_3: D28.2 (A), D33.2 (A), D38.2 (A), D43.2 (A), D48.2 (A), U3.2 (QC)
LED_COL_4: D29.2 (A), D34.2 (A), D39.2 (A), D44.2 (A), D49.2 (A), U3.3 (QD)
LED_COL_5: D30.2 (A), D35.2 (A), D40.2 (A), D45.2 (A), D50.2 (A), U3.4 (QE)
LED_ROW_1: R6.2, R7.2, R8.2, R9.2, R10.2, U4.15 (QA)
LED_ROW_2: R11.2, R12.2, R13.2, R14.2, R15.2, U4.1 (QB)
LED_ROW_3: R16.2, R17.2, R18.2, R19.2, R20.2, U4.2 (QC)
LED_ROW_4: R21.2, R22.2, R23.2, R24.2, R25.2, U4.3 (QD)
LED_ROW_5: R26.2, R27.2, R28.2, R29.2, R30.2, U4.4 (QE)
LT_COL_LED: DB1.28 (PG4), U3.12 (RCLK)
LT_ROW_LED: DB1.18 (PB4), U4.12 (RCLK)
LT_SW_IN: DB1.15 (PB7), U2.1 (~PL)
LT_SW_OUT: DB1.31 (PG0), U1.12 (RCLK)
unnamed: D1.2 (A), S1.2
unnamed: D2.2 (A), S2.2
unnamed: D3.2 (A), S3.2
unnamed: D4.2 (A), S4.2
unnamed: D5.2 (A), S5.2
unnamed: D6.2 (A), S6.2
unnamed: D7.2 (A), S7.2
unnamed: D8.2 (A), S8.2
unnamed: D9.2 (A), S9.2
unnamed: D10.2 (A), S10.2
unnamed: D11.2 (A), S11.2
unnamed: D12.2 (A), S12.2
unnamed: D13.2 (A), S13.2
unnamed: D14.2 (A), S14.2
unnamed: D15.2 (A), S15.2
unnamed: D16.2 (A), S16.2
unnamed: D17.2 (A), S17.2
unnamed: D18.2 (A), S18.2
unnamed: D19.2 (A), S19.2
unnamed: D20.2 (A), S20.2
unnamed: D21.2 (A), S21.2
unnamed: D22.2 (A), S22.2
unnamed: D23.2 (A), S23.2
unnamed: D24.2 (A), S24.2
unnamed: D25.2 (A), S25.2
unnamed: D26.1 (K), D51.2 (A)
unnamed: D27.1 (K), D52.2 (A)
unnamed: D28.1 (K), D53.2 (A)
unnamed: D29.1 (K), D54.2 (A)
unnamed: D30.1 (K), D55.2 (A)
unnamed: D31.1 (K), D56.2 (A)
unnamed: D32.1 (K), D57.2 (A)
unnamed: D33.1 (K), D58.2 (A)
unnamed: D34.1 (K), D59.2 (A)
unnamed: D35.1 (K), D60.2 (A)
unnamed: D36.1 (K), D61.2 (A)
unnamed: D37.1 (K), D62.2 (A)
unnamed: D38.1 (K), D63.2 (A)
unnamed: D39.1 (K), D64.2 (A)
unnamed: D40.1 (K), D65.2 (A)
unnamed: D41.1 (K), D66.2 (A)
unnamed: D42.1 (K), D67.2 (A)
unnamed: D43.1 (K), D68.2 (A)
unnamed: D44.1 (K), D69.2 (A)
unnamed: D45.1 (K), D70.2 (A)
unnamed: D46.1 (K), D71.2 (A)
unnamed: D47.1 (K), D72.2 (A)
unnamed: D48.1 (K), D73.2 (A)
unnamed: D49.1 (K), D74.2 (A)
unnamed: D50.1 (K), D75.2 (A)
unnamed: D51.1 (K), R6.1
unnamed: D52.1 (K), R7.1
unnamed: D53.1 (K), R8.1
unnamed: D54.1 (K), R9.1
unnamed: D55.1 (K), R10.1
unnamed: D56.1 (K), R11.1
unnamed: D57.1 (K), R12.1
unnamed: D58.1 (K), R13.1
unnamed: D59.1 (K), R14.1
unnamed: D60.1 (K), R15.1
unnamed: D61.1 (K), R16.1
unnamed: D62.1 (K), R17.1
unnamed: D63.1 (K), R18.1
unnamed: D64.1 (K), R19.1
unnamed: D65.1 (K), R20.1
unnamed: D66.1 (K), R21.1
unnamed: D67.1 (K), R22.1
unnamed: D68.1 (K), R23.1
unnamed: D69.1 (K), R24.1
unnamed: D70.1 (K), R25.1
unnamed: D71.1 (K), R26.1
unnamed: D72.1 (K), R27.1
unnamed: D73.1 (K), R28.1
unnamed: D74.1 (K), R29.1
unnamed: D75.1 (K), R30.1
unnamed: D76.1 (K), J1.A4 (VBUS), J1.A9 (VBUS), J1.B4 (VBUS), J1.B9 (VBUS)
unnamed: J1.A5 (CC1), R34.1
unnamed: J1.B5 (CC2), R35.2
RES_SPI: DB1.7 (PE9), U5.5 (RES)
SCL_SPI: DB1.5 (PE11), U5.3 (SCL)
SDA_SPI: DB1.6 (PE10), U5.4 (SDA)
SER_COL_LED: DB1.30 (PG3), U3.14 (SER)
SER_ROW_LED: DB1.16 (PB6), U4.14 (SER)
SER_SW_IN: DB1.13 (PE0), U2.9 (Q7)
SER_SW_OUT: DB1.33 (PG1), U1.14 (SER)
SW_COL_1: S1.1, S6.1, S11.1, S16.1, S21.1, U1.15 (QA)
SW_COL_2: S2.1, S7.1, S12.1, S17.1, S22.1, U1.1 (QB)
SW_COL_3: S3.1, S8.1, S13.1, S18.1, S23.1, U1.2 (QC)
SW_COL_4: S4.1, S9.1, S14.1, S19.1, S24.1, U1.3 (QD)
SW_COL_5: S5.1, S10.1, S15.1, S20.1, S25.1, U1.4 (QE)
SW_DER: DB1.10 (PE6), R33.2, S28.2
SW_ENT: DB1.11 (PE5), R32.2, S27.2
SW_IZQ: DB1.12 (PE4), R31.2, S26.2
SW_ROW_1: D1.1 (K), D2.1 (K), D3.1 (K), D4.1 (K), D5.1 (K), R1.2, U2.11 (D0)
SW_ROW_2: D6.1 (K), D7.1 (K), D8.1 (K), D9.1 (K), D10.1 (K), R2.2, U2.12 (D1)
SW_ROW_3: D11.1 (K), D12.1 (K), D13.1 (K), D14.1 (K), D15.1 (K), R3.2, U2.13 (D2)
SW_ROW_4: D16.1 (K), D17.1 (K), D18.1 (K), D19.1 (K), D20.1 (K), R4.2, U2.14 (D3)
SW_ROW_5: D21.1 (K), D22.1 (K), D23.1 (K), D24.1 (K), D25.1 (K), R5.2, U2.3 (D4)

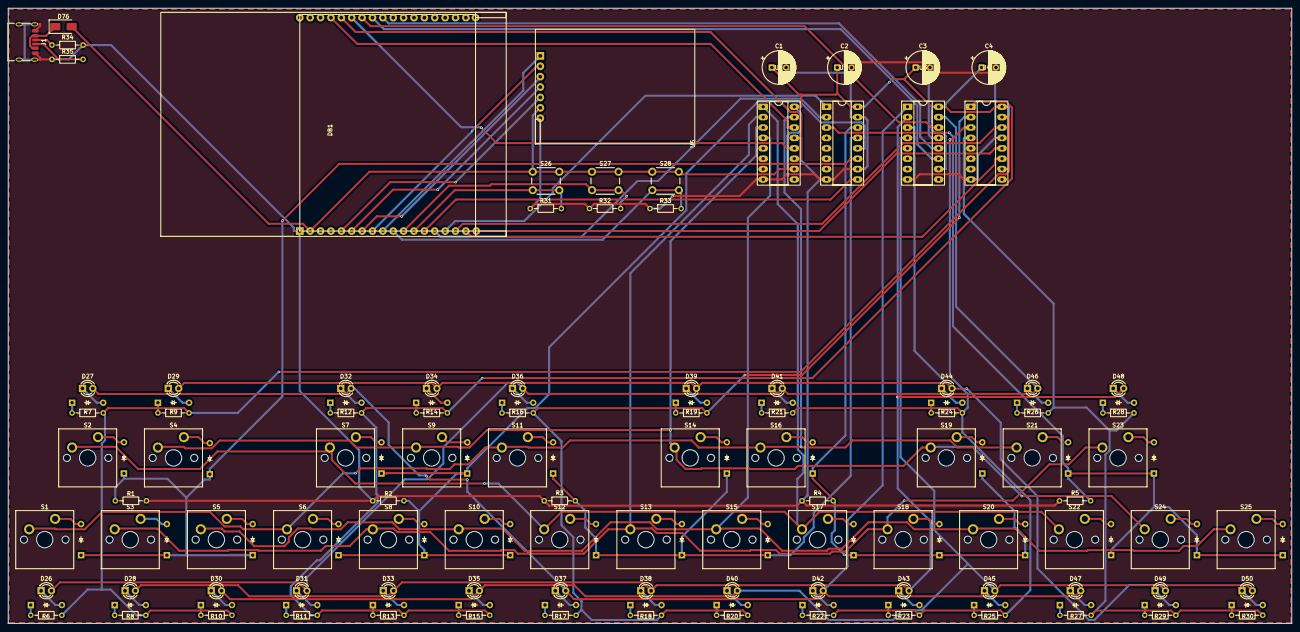
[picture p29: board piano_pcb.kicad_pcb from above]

Board: 2 copper layers, 314.0 x 150.5 mm, 150 parts (0 on the bottom side), 120 nets.

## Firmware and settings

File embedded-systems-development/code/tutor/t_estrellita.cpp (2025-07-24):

#include <gpiod.h>
#include <unistd.h>
#include <iostream>
#include <vector>
#include <string>
#include <map>
#include <csignal>
#include <sys/types.h>
#include <sys/wait.h>

#define CHIPNAME "gpiochip0"
#define CONSUMER "tutor-estrellita"

#define PIN_SER_OUT   193
#define PIN_CLK_OUT   194
#define PIN_LATCH_OUT 192
#define PIN_SER_IN    128
#define PIN_CLK_IN    129
#define PIN_LATCH_IN   39

#define PIN_SER_COL   195
#define PIN_CLK_COL   197
#define PIN_LATCH_COL 196
#define PIN_SER_ROW   38
#define PIN_CLK_ROW   37
#define PIN_LATCH_ROW 36

const char* notes[5][5] = {
    {"C4",  "F4",  "A#4", "D#5", "G#5"},
    {"C#4", "F#4", "B4",  "E5",  "A5"},
    {"D4",  "G4",  "C5",  "F5",  "A#5"},
    {"D#4", "G#4", "C#5", "F#5", "B5"},
    {"E4",  "A4",  "D5",  "G5",  "C6"}
};

const std::vector<std::string> melodia = {
    "C4", "C4", "G4", "G4", "A4", "A4", "G4",
    "F4", "F4", "E4", "E4", "D4", "D4", "C4",
    "G4", "G4", "F4", "F4", "E4", "E4", "D4",
    "G4", "G4", "F4", "F4", "E4", "E4", "D4",
    "C4", "C4", "G4", "G4", "A4", "A4", "G4",
    "F4", "F4", "E4", "E4", "D4", "D4", "C4"
};

gpiod_chip *chip;
gpiod_line *serOut, *clkOut, *latchOut;
gpiod_line *serIn, *clkIn, *latchIn;
gpiod_line *serCol, *clkCol, *latchCol;
gpiod_line *serRow, *clkRow, *latchRow;

std::map<std::string, pid_t> procesosActivos;
std::map<std::string, std::pair<int, int>> noteToPosition;

void pulse(gpiod_line* line) {
    gpiod_line_set_value(line, 1);
    usleep(1);
    gpiod_line_set_value(line, 0);
    usleep(1);
}

bool setup() {
    chip = gpiod_chip_open_by_name(CHIPNAME);
    if (!chip) return false;

    serOut = gpiod_chip_get_line(chip, PIN_SER_OUT);
    clkOut = gpiod_chip_get_line(chip, PIN_CLK_OUT);
    latchOut = gpiod_chip_get_line(chip, PIN_LATCH_OUT);
    serIn = gpiod_chip_get_line(chip, PIN_SER_IN);
    clkIn = gpiod_chip_get_line(chip, PIN_CLK_IN);
    latchIn = gpiod_chip_get_line(chip, PIN_LATCH_IN);

    serCol = gpiod_chip_get_line(chip, PIN_SER_COL);
    clkCol = gpiod_chip_get_line(chip, PIN_CLK_COL);
    latchCol = gpiod_chip_get_line(chip, PIN_LATCH_COL);
    serRow = gpiod_chip_get_line(chip, PIN_SER_ROW);
    clkRow = gpiod_chip_get_line(chip, PIN_CLK_ROW);
    latchRow = gpiod_chip_get_line(chip, PIN_LATCH_ROW);

    if (!serOut || !clkOut || !latchOut || !serIn || !clkIn || !latchIn ||
        !serCol || !clkCol || !latchCol || !serRow || !clkRow || !latchRow)
        return false;

    if (gpiod_line_request_output(serOut, CONSUMER, 0) < 0 ||
        gpiod_line_request_output(clkOut, CONSUMER, 0) < 0 ||
        gpiod_line_request_output(latchOut, CONSUMER, 0) < 0 ||
        gpiod_line_request_input(serIn, CONSUMER) < 0 ||
        gpiod_line_request_output(clkIn, CONSUMER, 0) < 0 ||
        gpiod_line_request_output(latchIn, CONSUMER, 0) < 0 ||
        gpiod_line_request_output(serCol, CONSUMER, 0) < 0 ||
        gpiod_line_request_output(clkCol, CONSUMER, 0) < 0 ||
        gpiod_line_request_output(latchCol, CONSUMER, 0) < 0 ||
        gpiod_line_request_output(serRow, CONSUMER, 0) < 0 ||
        gpiod_line_request_output(clkRow, CONSUMER, 0) < 0 ||
        gpiod_line_request_output(latchRow, CONSUMER, 0) < 0)
        return false;

    return true;
}

void shiftOutKeys(uint8_t val) {
    for (int i = 7; i >= 0; --i) {
        int bit = (val >> i) & 1;
        gpiod_line_set_value(serOut, bit);
        pulse(clkOut);
    }
    pulse(latchOut);
}

uint8_t shiftIn() {
    gpiod_line_set_value(latchIn, 0);
    usleep(1);
    gpiod_line_set_value(latchIn, 1);
    usleep(1);

    uint8_t value = 0;
    for (int i = 0; i < 8; ++i) {
        pulse(clkIn);
        int bit = gpiod_line_get_value(serIn);
        value = (value << 1) | (bit & 1);
    }
    return value;
}

void shiftOut(gpiod_line* data, gpiod_line* clk, gpiod_line* latch, uint8_t val) {
    for (int i = 7; i >= 0; --i) {
        int bit = (val >> i) & 1;
        gpiod_line_set_value(data, bit);
        pulse(clk);
    }
    pulse(latch);
}

void tocarNota(const std::string& nota) {
    if (procesosActivos.count(nota) == 0) {
        pid_t pid = fork();
        if (pid == 0) {
            execl(("./bin/" + nota).c_str(), nota.c_str(), nullptr);
            _exit(1);
        }
        procesosActivos[nota] = pid;
    }
}

void apagarNota(const std::string& nota) {
    if (procesosActivos.count(nota)) {
        pid_t pid = procesosActivos[nota];
        kill(pid, SIGTERM);
        waitpid(pid, nullptr, 0);
        procesosActivos.erase(nota);
    }
}

void apagarTodas() {
    for (auto& [nota, pid] : procesosActivos) {
        kill(pid, SIGTERM);
        waitpid(pid, nullptr, 0);
    }
    procesosActivos.clear();
}

void lightNote(std::string nota) {
    auto it = noteToPosition.find(nota);
    if (it == noteToPosition.end()) return;
    int col = it->second.first;
    int row = it->second.second;
    uint8_t colMask = 1 << col;
    uint8_t rowMask = ~(1 << row);
    shiftOut(serCol, clkCol, latchCol, colMask);
    shiftOut(serRow, clkRow, latchRow, rowMask);
}

int main() {
    if (!setup()) {
        std::cerr << "Error al inicializar GPIO\n";
        return 1;
    }

    for (int col = 0; col < 5; ++col)
        for (int row = 0; row < 5; ++row)
            noteToPosition[notes[col][row]] = {col, row};

    for (const auto& nota : melodia) {
        std::cout << "Toca la nota: " << nota << std::endl;
        lightNote(nota);

        bool notaPresionada = false;
        std::map<std::string, bool> estadoAnterior;

        while (!notaPresionada) {
            std::map<std::string, bool> estadoActual;

            for (int col = 0; col < 5; ++col) {
                uint8_t colMask = 1 << col;
                shiftOutKeys(colMask);
                usleep(100);
                uint8_t rawRowState = shiftIn();
                uint8_t rowState = rawRowState >> 1;

                for (int row = 0; row < 5; ++row) {
                    std::string notaLeida = notes[col][row];
                    bool presionada = (rowState & (1 << row));
                    estadoActual[notaLeida] = presionada;

                    if (presionada && !estadoAnterior[notaLeida]) {
                        tocarNota(notaLeida);
                    } else if (!presionada && estadoAnterior[notaLeida]) {
                        apagarNota(notaLeida);
                    }

                    if (notaLeida == nota && presionada) {
                        notaPresionada = true;
                    }
                }
            }
            estadoAnterior = estadoActual;
            usleep(20000);
        }

        usleep(1000000);
        apagarNota(nota);
    }

    apagarTodas();
    shiftOut(serCol, clkCol, latchCol, 0);
    shiftOut(serRow, clkRow, latchRow, 0);
    gpiod_chip_close(chip);
    return 0;
}

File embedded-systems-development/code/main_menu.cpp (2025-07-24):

#include <gpiod.h>
#include <unistd.h>
#include <iostream>
#include <csignal>
#include <sys/wait.h>

#define CHIPNAME "gpiochip0"
#define PIN_IZQ 132
#define PIN_ENT 133
#define PIN_DER 134

enum EstadoMenu { RAIZ, SELECCION_MODO, MODO_TUTOR, MODO_NORMAL };
enum OpcionRaiz { NORMAL, TUTOR };
enum CancionTutor { ESTRELLITA, HBD, PIRATAS, POLLITOS };

gpiod_chip *chip;
gpiod_line *btnIzq, *btnEnt, *btnDer;

bool setup() {
    chip = gpiod_chip_open_by_name(CHIPNAME);
    if (!chip) return false;

    btnIzq = gpiod_chip_get_line(chip, PIN_IZQ);
    btnEnt = gpiod_chip_get_line(chip, PIN_ENT);
    btnDer = gpiod_chip_get_line(chip, PIN_DER);

    if (!btnIzq || !btnEnt || !btnDer) return false;

    if (gpiod_line_request_input(btnIzq, "menu") < 0 ||
        gpiod_line_request_input(btnEnt, "menu") < 0 ||
        gpiod_line_request_input(btnDer, "menu") < 0)
        return false;

    return true;
}

bool presionado(gpiod_line* btn) {
    return gpiod_line_get_value(btn) == 1;
}

void esperar_liberacion() {
    while (presionado(btnIzq) || presionado(btnEnt) || presionado(btnDer)) {
        usleep(50000);
    }
    usleep(150000); // debounce
}

void mostrar(const std::string& imagen) {
    if (fork() == 0) {
        execl(("./" + imagen).c_str(), imagen.c_str(), nullptr);
        _exit(1);
    } else {
        int status;
        wait(&status);
    }
}

void ejecutar_con_escape(const std::string& binario) {
    pid_t pid = fork();
    if (pid == 0) {
        execl(("./" + binario).c_str(), binario.c_str(), nullptr);
        _exit(1);
    }

    // Proceso padre: monitorea botones mientras ejecuta el hijo
    while (true) {
        if (presionado(btnEnt) && presionado(btnDer)) {
            kill(pid, SIGTERM);
            waitpid(pid, nullptr, 0);
            break;
        }

        int status;
        pid_t result = waitpid(pid, &status, WNOHANG);
        if (result == pid) break; // terminó naturalmente

        usleep(100000); // 100ms
    }

    esperar_liberacion();
}

void ejecutar(const std::string& binario) {
    if (fork() == 0) {
        execl(("./" + binario).c_str(), binario.c_str(), nullptr);
        _exit(1);
    } else {
        int status;
        wait(&status);
    }
}

int main() {

    ejecutar("apagar_leds");

    if (!setup()) {
        std::cerr << "Error al inicializar botones GPIO\n";
        return 1;
    }

    EstadoMenu estado = RAIZ;
    OpcionRaiz opcion = NORMAL;
    CancionTutor cancion = ESTRELLITA;

    mostrar("o_menu_normal");

    while (true) {
        bool izq = presionado(btnIzq);
        bool der = presionado(btnDer);
        bool ent = presionado(btnEnt);

        // Volver atrás si se presionan ENTER + DERECHA
        if (ent && der) {
            if (estado == MODO_TUTOR || estado == MODO_NORMAL) {
                estado = RAIZ;
                mostrar("o_menu_normal");
                esperar_liberacion();
                continue;
            }
        }

        if (estado == RAIZ) {
            if (izq || der) {
                opcion = (opcion == NORMAL) ? TUTOR : NORMAL;
                mostrar(opcion == NORMAL ? "o_menu_normal" : "o_menu_tutor");
                esperar_liberacion();
            } else if (ent) {
                if (opcion == NORMAL) {
                    mostrar("o_normal");
                    estado = MODO_NORMAL;
                    ejecutar_con_escape("read_notes");
                    mostrar("o_menu_normal");
                    estado = RAIZ;
                } else {
                    estado = MODO_TUTOR;
                    cancion = ESTRELLITA;
                    mostrar("o_t_estrellita");
                    esperar_liberacion();
                }
            }
        }

        else if (estado == MODO_TUTOR) {
            if (izq) {
                cancion = static_cast<CancionTutor>((cancion + 3) % 4);
                switch (cancion) {
                    case ESTRELLITA: mostrar("o_t_estrellita"); break;
                    case HBD:         mostrar("o_t_hbd"); break;
                    case PIRATAS:     mostrar("o_t_piratas"); break;
                    case POLLITOS:    mostrar("o_t_pollitos"); break;
                }
                esperar_liberacion();
            } else if (der) {
                cancion = static_cast<CancionTutor>((cancion + 1) % 4);
                switch (cancion) {
                    case ESTRELLITA: mostrar("o_t_estrellita"); break;
                    case HBD:         mostrar("o_t_hbd"); break;
                    case PIRATAS:     mostrar("o_t_piratas"); break;
                    case POLLITOS:    mostrar("o_t_pollitos"); break;
                }
                esperar_liberacion();
            } else if (ent) {
                switch (cancion) {
                    case ESTRELLITA: ejecutar("t_estrellita"); break;
                    case HBD:         ejecutar("t_hbd"); break;
                    case PIRATAS:     ejecutar("t_piratas"); break;
                    case POLLITOS:    ejecutar("t_pollitos"); break;
                }
                mostrar("o_menu_normal");
                estado = RAIZ;
                esperar_liberacion();
            }
        }

        usleep(100000); // 100ms
    }

    gpiod_chip_close(chip);
    return 0;
}

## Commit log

2025-07-25 Update electronic-system-design folder
    [bom.csv, designators.csv, piano_pcb.kicad_pcb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]
2025-07-25 Update PCB files
2025-07-25 Update case files
2025-07-25 Update Prototype and Improvements section
